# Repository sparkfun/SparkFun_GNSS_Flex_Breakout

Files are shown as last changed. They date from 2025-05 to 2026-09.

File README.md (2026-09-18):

SparkFun GNSS Flex Breakout
========================================

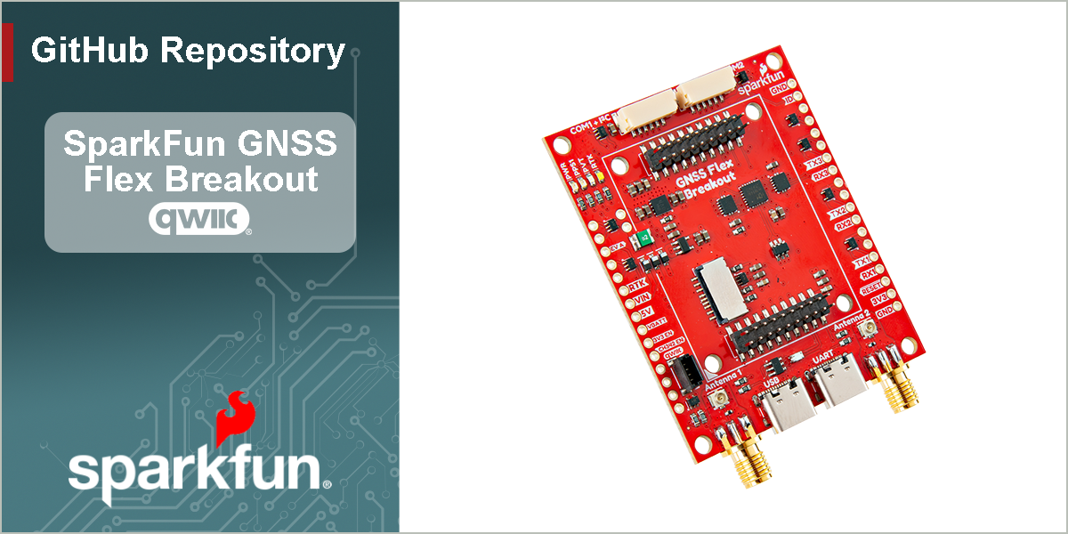
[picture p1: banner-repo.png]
SparkFun GNSS Flex Breakout


[*SparkFun GNSS Flex Breakout (GPS-28962)*](https://www.sparkfun.com/sparkfun-gnss-flex-breakout.html)

The [SparkFun GNSS Flex breakout](https://www.sparkfun.com/sparkfun-gnss-flex-breakout.html) is a *carrier board* for our GNSS Flex modules. In its simplest form, the GNSS Flex Breakout board provides access to all of the interfaces from a GNSS Flex module.

- Need access to all those UART pins? The Breakout provides that.
- Want to communicate with the GNSS directly over USB? You can do that too, if the GNSS module supports USB.

The GNSS Flex Breakout comes populated with two sets of 2x10 pin, 2mm pitch male headers for attaching a GNSS Flex module. With these headers, the GNSS Flex system is designed to be modular so that boards are pin-compatible for upgrades and can be easily swapped for repairs. Depending on the capabilities of the GNSS Flex module that is connected, these pins will breakout the USB, UART (x4), I^2^C, and SD card interfaces for the GNSS receiver along with any PPS (x2) or event (x2) signals, using a standardized pin out.

By default, the CH342 USB-to-Serial converter chip is connected to both the GNSS `UART1` and `UART2` interfaces. When you connect the `UART` USB port to your computer and install the driver, those two UART interfaces will appear as COM ports. If you need dedicated access to the `UART1` or `UART2` breakout pins, or want to use either of the JST connectors, you will need to disable the CH342. On this board, we have made this simple; just pull the `CH342 EN` breakout pin `LOW` or connect it to `GND`. Otherwise, there is also a `CH342 EN` jumper you can solder instead.

We have also included two 6-pin JST connectors, same as the ones used on Pixhawk flight controllers. The JST connectors allow you to: connect the GNSS to a Pixhawk; or connect a radio to the GNSS to transfer (e.g.) RTCM correction data. There are four LEDs indicators for power to the board and the `PPS1`, `PVT`, and `RTK` signals from the GNSS Flex module. Power can be provided by any or all of: the USB connectors or the `VIN` breakout pin. By default, Pin 1 of the JST connectors provides 5V output. But jumpers on the board allow the voltage to be changed to 3.3V. Or you can isolate the other power sources and connect an external 5V power input on Pin 1 instead. It is up to you.

> [!IMPORTANT]
> Depending on the GNSS Flex module, this product will likely require an external antenna:
>
> - Be sure to check out the hookup guide for more information on the GNSS Flex module.
> - Users can also find [GNSS Antennas](https://www.sparkfun.com/gnss/gnss-antennas.html) in our catalog.
>
> Users will have two options for connecting an external GNSS antenna to their GNSS receiver.
>
> - The GNSS Flex modules will usually come with a U.FL connector for external antenna.
> - For a sturdier connection, an SMA connector is available on the SparkFun GNSS Flex Breakout that is bridged to an U.FL connector. Users simply need to jumper the U.FL connectors on both the SparkPNT GNSS Flex module and SparkFun GNSS Flex Breakout with a short U.FL cable.

Documentation
--------------
- **[Hookup Guide (mkdocs)](http://docs.sparkfun.com/SparkFun_GNSS_Flex_System/)** - A hookup guide for the entire ecosystem of SparkFun GNSS Flex carrier boards and SparkPNT GNSS Flex modules, hosted by GitHub pages.<br>
   

Repository Contents
-------------------
- **[/docs](/docs/)** - Online documentation files
  - [/assets](/docs/assets/) - Assets files
    - [/3d_model](/docs/assets/3d_model/) - Files for the 3D models
      - [/3D CAD Model](/docs/assets/3d_model/cad_model.step) (.step)
    - [/board_files](/docs/assets/board_files/) - Files for the product design
      - [KiCad Design Files](/docs/assets/board_files/kicad_files.zip) (.zip)
      - [Schematic](/docs/assets/board_files/schematic.pdf) (.pdf)
      - [Dimensions](/docs/assets/board_files/dimensions.pdf) (.pdf)
    - [/component_documentation](/docs/assets/component_documentation/) - Datasheets for hardware components
    - [/img/hookup_guide/](/docs/assets/img/hookup_guide/) - Images for hookup guide documentation
- **[/Hardware](/Hardware/)** - Hardware design files (.brd, .sch)
  - **[/Production](/Production/)** - Production files

Product Variants
----------------
GNSS Flex *Carrier* Boards:

- [GPS-28962](https://www.sparkfun.com/sparkfun-gnss-flex-breakout.html) - GNSS Flex Breakout
- [GPS-28137](https://www.sparkfun.com/sparkfun-gnss-flex-phat.html) - GNSS Flex pHAT

Version History
---------------
- [v10](https://github.com/sparkfun/SparkFun_GNSS_Flex_Breakout/releases/tag/v10) - Initial Release
- [v11](https://github.com/sparkfun/SparkFun_GNSS_Flex_Breakout/releases/tag/v11) - Refactored the 3D model for new color adjustment script

License Information
-------------------

This product is ***open source***!

Please review the [`LICENSE.md`](./LICENSE.md) file for license information.

If you have any questions or concerns about licensing, please contact technical support on our [SparkFun forums](https://community.sparkfun.com/).

Distributed as-is; no warranty is given.

- Your friends at SparkFun.

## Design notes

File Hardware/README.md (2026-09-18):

SparkFun <PRODUCT NAME> Design Files
=====================================

The .sch and .brd files hare are Eagle CAD schematic and PCB design files from SparkFun Electronics.
A freeware version of Autodesk Eagle can be found [here](https://www.autodesk.com/products/eagle/free-download).

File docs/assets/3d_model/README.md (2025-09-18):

3d_model directory
====================
This folder should contain the 3D model of the product

## Solder Mask - Color Correction Values
Hex: #E0311D
RGB: 224, 49, 29

## File Optimizer
https://xiehangyun.github.io/gltf-optimization/

- Max Texture Size: 512
- Create Unified Palette Texture for Solid Colors and Merge: *(Unselect)*

## Model Editor
https://modelviewer.dev/editor/

## Old Methods

### File Converter - `*.wrl` to `*.glb`
https://imagetostl.com/convert/file/wrl/to/glb#convert

### Solder Mask - Color Correction
Open `*.glb` file and locate the `baseColorFactor` parameter with the following values:
```
          0.7027450799942017,
          0.1537254899740219,
          0.0909803956747055,
          0.8313725590705872
```
Replace those values with the following values: `[,,,1]`
```
          0.7418950796127319,
          0.0302486829459667,
          0.0122311776503920,
          1
```

### Solder Mask - Color Correction
https://3deditoronline.com/

### File Optimizer *(Deprecated)*
https://www.loci-labs.com/optimizer

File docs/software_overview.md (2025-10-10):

## USB Drivers
Depending on the GNSS Flex module that is attached, users may need to install specific USB driver. However, to access the UART interfaces through the `UART` USB-C connector, users will need to install the [CH342 USB driver](#ch342-usb-driver) below.

### CH342 USB Driver
The USB drivers for the CH342 USB-to-Serial converter can be downloaded from the [manufacturer's website](https://www.wch-ic.com/search?q=CH342&t=downloads).

<div class="grid cards" align="center" markdown>

-   :material-microsoft-windows: **Windows**

	---

	[:octicons-download-16:{ .heart } Download Page for `CH343SER.EXE`](https://www.wch-ic.com/downloads/CH343SER_EXE.html){ .md-button .md-button--primary target="blank" }

-   :material-apple: **MacOS**

	---

	[:octicons-download-16:{ .heart } Download Page for `CH341SER_MAC.ZIP`](https://www.wch-ic.com/downloads/CH34XSER_MAC_ZIP.html){ .md-button .md-button--primary target="blank" }

</div>

!!! info "Linux"
	A USB driver is not required for Linux based operating systems.

### GNSS Receiver
Some GNSS receivers may require a USB driver to be installed, before users can connect to its USB interface. For example, the ZED-X20P GNSS receiver does not require a USB drive to be installed to access its USB interface for development purposes; meanwhile, the mosaic-X5 GNSS receiver does require a USB driver to be installed before it can be connected to a Windows OS computer.

!!! info
	For more details on a specific GNSS Flex module, please refer to their [hookup guide](../modules.md).

## Manufacturer Software
Most of the manufacturers will provide software that is designed to specifically operate and configure their GNSS receivers. Often, this is the simplest way to get started with any development. The software usually provides a graphical interface for evaluating the GNSS receiver's performance, configuring any settings, and upgrading the firmware. Below are general software resources that might be useful; however, users should refer to the [hookup guide of their GNSS Flex module](../modules.md) for more details on a specific board.

<div class="grid cards" markdown>

- :septentrio:septentrio

	---

	On Windows & Linux platforms, Septentrio provides the RxTools software suite for their GNSS products:

	- [Software Page](https://www.septentrio.com/en/products/gps-gnss-receiver-software/rxtools)
	- [Download & User Manual](https://www.septentrio.com/en/products/gps-gnss-receiver-software/rxtools#resources)
	- [Tutorial Videos](https://www.youtube.com/playlist?list=PLUxLg2_PvvdHZ73CnfhS7ZePIIIUR7bON)

- <span class="twemoji enlarge-logo" style="width: 100%;">:quectel-primary:</span>

	---

	On Windows platforms, Quectel provides the QGNSS *(v2.0)* software application for their GNSS products:

	- [Download & User Manual](https://www.quectel.com/download/qgnss_v2-1_en/)
	- [GitHub Repository](https://github.com/quectel-open-source/GNSSTool)

- :ublox-primary:{ .icon-max-width }

	---

	On Windows platforms, u-blox provides the [u-center 2](https://www.u-blox.com/en/u-center-2) software application for their GNSS products:

	- [Software Page](https://www.u-blox.com/en/product/u-center)
	- [Download](https://u-center2-updates.u-blox.com/u-center2-installer.exe)
	- [User Manual](https://www.u-blox.com/en/info/u-center-2-user-guide)
	- [Webinar](https://www.youtube.com/watch?v=ZYttFyZ_7Uo)
	- [Tutorial Videos](https://www.youtube.com/watch?v=UY2XTb72SXA&list=PLSzSoRUA4EXuo9NTsbTnK84MiKvbVCEKt)

</div>

## Third-Party Software
In addition to any software provided by the manufacturers, there are a variety of third-party software options. The software implementation may even be unique to the available interfaces from an associated *carrier* board.

<div class="grid cards" markdown>

-   **PyGPSClient**

	---

	The `PyGPSClient` Python package is a graphical tool for evaluating the basic performance of GNSS receivers and is compatible with most of the major operating systems. The application parses and extrapolates a variety of data from the UART interface of GNSS receivers; with integrated support for the **NMEA**, **UBX**, **RTCM**, **NTRIP**, and **SPARTN** protocols. All GNSS information is then displayed neatly within its GUI for users to access or utilize.

	- [PyPI - Python Package](https://pypi.org/project/pygpsclient/)
	- [User Manual](https://www.semuconsulting.com/pygpsclient/index.html)
	- [GitHub Repository](https://github.com/semuconsulting/PyGPSClient)

</div>

### Installation
There are a variety of [installation methods](https://github.com/semuconsulting/PyGPSClient?tab=readme-ov-file#installation) detailed in the GitHub repository's `README.md` file. However, we recommend utilizing either the [`pip` installation method](https://github.com/semuconsulting/PyGPSClient?tab=readme-ov-file#install-using-pip). Depending on how Python is installed on the computer, one of the following commands should allow users to install the software:

```shell
python3 -m pip install pygpsclient
```

```shell
pip3 install pygpsclient
```

### NTRIP Client

<div class="grid" markdown>

<div markdown>

<figure markdown>
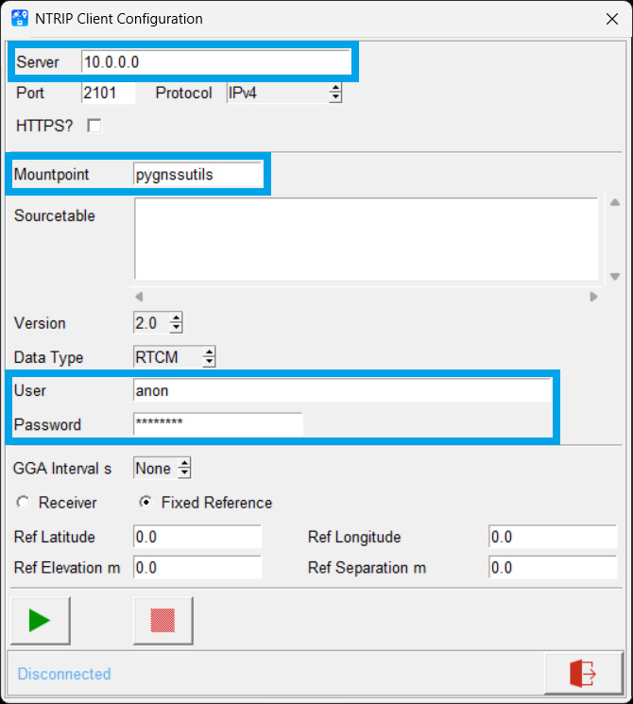
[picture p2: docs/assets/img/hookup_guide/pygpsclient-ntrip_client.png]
NTRIP server configurations

<figcaption markdown>Configuration settings for connecting to an NTRIP client.</figcaption>
</figure>

</div>

<div markdown>

To receive and process NTRIP RTK correction data from an NTRIP server in the PyGPSClient software, users can follow [these instructions](https://github.com/semuconsulting/PyGPSClient?tab=readme-ov-file#ntrip-client-facilities):

1. Click on the :material-satellite-uplink: icon, labeled `NTRIP Client`.
1. Enter the information for the network and mount point.
	- For an NTRIP server hosted by the `PyGPSClient` software:
		- **Server:** IP address of computer
		- **Port:** `2101`
		- **Mountpoint:** `pygnssutils`
		- **User:** `anon`
		- **Password:** `password`
1. Click on the :material-play: icon to connect to the server.

</div>

</div>

### NTRIP Server

<div class="grid" markdown>

<div markdown>

<figure markdown>
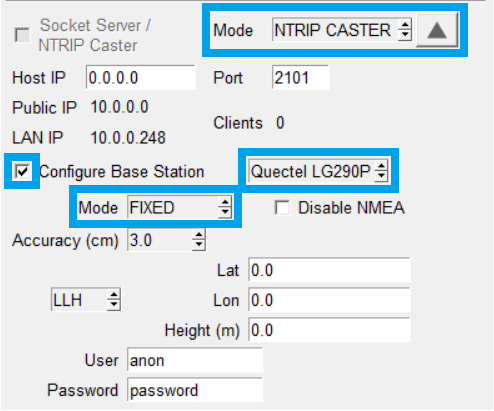
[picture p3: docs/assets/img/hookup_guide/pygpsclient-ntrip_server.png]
NTRIP server configurations

<figcaption markdown>Configuration settings for an NTRIP caster.</figcaption>
</figure>

</div>

<div markdown>

If their GNSS receiver is supported by NTRIP sever feature of the PyGPSClient software, users can follow [these instructions](https://github.com/semuconsulting/PyGPSClient?tab=readme-ov-file#socket-server--ntrip-caster-facilities) to setup their computer to operate as an NTRIP sever:

1. In the settings console, scroll to the bottom and select `NTRIP CASTER` from the **Mode** drop-down menu.
1. Select the box for `Configure Base Station` and select the GNSS receiver from the drop-down menu.
1. Select a mode of operation for the base station and provide the necessary information.
1. Select the box for `Socket Server/NTRIP Caster`.

</div>

</div>

## Arduino Libraries
There are some compatible Arduino libraries available for users interested in connecting their GNSS Flex module to a microcontroller.

### TinyGPS++ Library
For basic use cases, where users have already pre-configured their GNSS receiver, the [TinyGPS++ Arduino library](https://github.com/mikalhart/TinyGPSPlus) can be used to parse out pertinent data from the NMEA messages of their GNSS receiver. This is useful for extracting basic information, such as position, date, time, altitude, speed, and course from consumer GPS devices. This library can be installed from the library manager in the Arduino IDE by searching for:

	TinyGPSPlus

<div class="grid" markdown>

<div markdown>

<figure markdown>
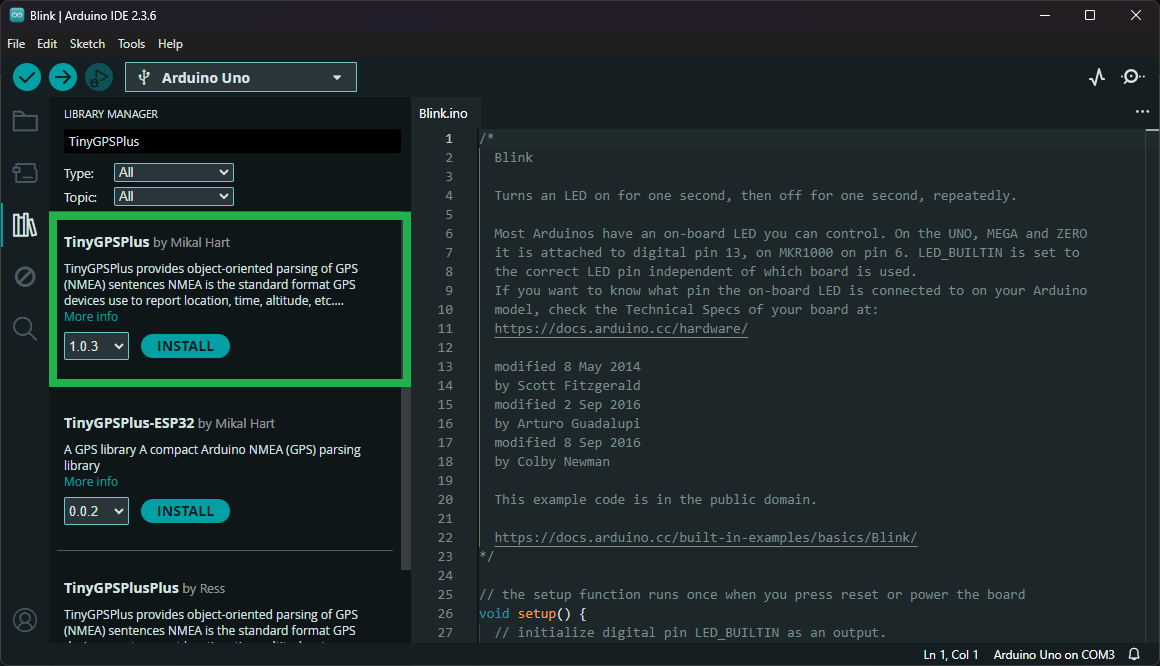
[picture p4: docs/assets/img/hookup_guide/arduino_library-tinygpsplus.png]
Library listed in the library manager of the Arduino IDE Click to enlarge

<figcaption markdown>The `TinyPGSPlus` Arduino library in the library manager of the Arduino IDE.</figcaption>
</figure>

</div>

<div markdown>

!!! tip "Manually Download the Arduino Library"
	For users who would like to manually download and install the library, the `*.zip` file can be accessed from the [GitHub repository](https://github.com/mikalhart/TinyGPSPlus) or downloaded by clicking the button below.

	<article style="text-align: center;" markdown>
	[:octicons-download-16:{ .heart } Download the Arduino Library](https://github.com/mikalhart/TinyGPSPlus/archive/refs/heads/master.zip){ .md-button .md-button--primary }
	</article>

</div>

</div>

### Receiver Specific Libraries
Some GNSS receivers may have a compatible Arduino library. As an example, the mosaic-X5 GNSS receiver has an inordinate amount of configuration parameters and is most readily configured through its web interface; therefore, an Arduino library hasn't been created for it. Whereas, the ZED-X20P GNSS receiver has a pre-existing [SparkFun u-blox GNSS v3](https://github.com/mikalhart/TinyGPSPlus) Arduino library that includes built-in examples, which the GNSS receiver is compatible with.

!!! info
	Please refer to the [hookup guide of your GNSS Flex module](../modules.md) for more details.

???+ note
	## mosaic-X5 Web Interface
	The mosaic-X5 GNSS module hosts an internal web server to configure and interact with the GNSS receiver. The default IP address allocated to the Ethernet-over-USB connection is `192.168.3.1`. This IP can be entered in any browser to open a connection to the receiver's web interface.

	<article class="video-500px" style="margin: auto;" markdown>
	<iframe src="https://www.youtube.com/embed/hrL5J6Q5gX8" title="Septentrio: Getting started with the Septentrio mosaic receiver module" frameborder="0" allow="accelerometer; autoplay; clipboard-write; encrypted-media; gyroscope; picture-in-picture" allowfullscreen></iframe>
	</article>

	!!! info
		The default IP address cannot be changed; this feature is only to be used when a single receiver is connected to your computer.

	### Sharing Internet Access
	By default, the mosaic-X5 GNSS receiver is not configured to access the internet through the USB interface. In order to receive or cast RTK corrections to/from a RTK network, such as NTRIP, users will need to enable this capability.

	- Users will need to use the web interface or RxTool software suite to enable the `Outgoing Internet Access Over USB` from the **Communication** > **USB** drop-down menu of the navigation tabs.
	- This also requires users to allowing Internet sharing through on their computer as well. The procedure to do so depends on your operating system.
		- On a Windows PC, users must enable `Allow other network users to connect through this computer's Internet connection`, through the properties option of the network adapter with internet access.
		- On a Linux computer, users will likely need to configure a [network bridge](https://en.wikipedia.org/wiki/Network_bridge).

	<article class="video-500px" style="margin: auto;" markdown>
	<iframe src="https://www.youtube.com/embed/bUt8cL9Ue1Y" title="Septentrio: Share internet connection with your GNSS / GPS receiver over USB" frameborder="0" allow="accelerometer; autoplay; clipboard-write; encrypted-media; gyroscope; picture-in-picture" allowfullscreen></iframe>
	</article>

	!!! info "New IP Address"
		Once a network bridge is enabled, the receiver will receive its IP address from the computer's DHCP server. Depending on the routing table, the module may no longer be reachable at its default IP address *(`192.168.3.1`)*.

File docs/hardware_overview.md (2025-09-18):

<article style="text-align: center;" markdown>
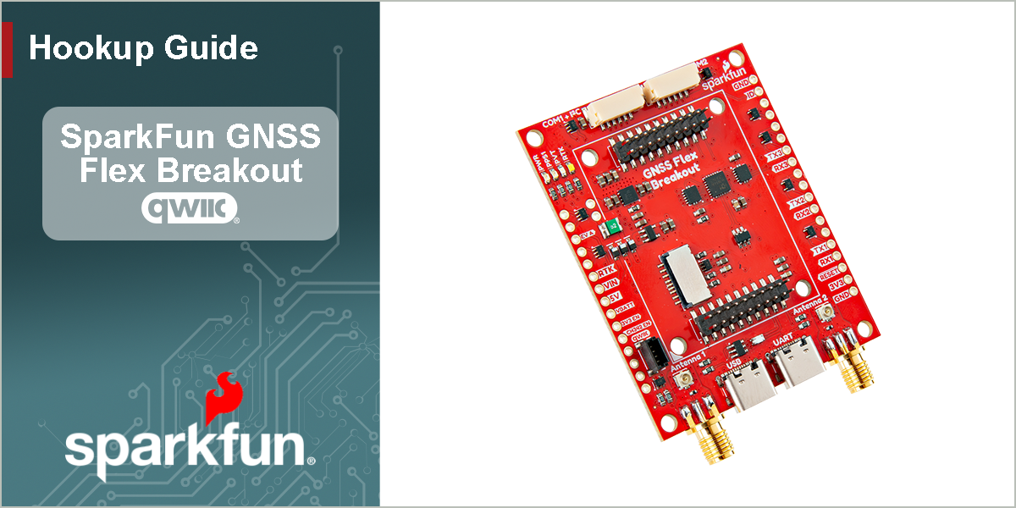
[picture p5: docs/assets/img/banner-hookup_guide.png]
Banner

</article>

## Introduction

<div class="grid cards desc" markdown>

-   <a href="https://www.sparkfun.com/sparkfun-gnss-flex-breakout.html">
	**SparkFun GNSS Flex Breakout**<br>
	**SKU:** GPS-28137

	---

	<figure markdown>
	Product Thumbnail
	</figure></a>

	<article style="text-align: center;" markdown>
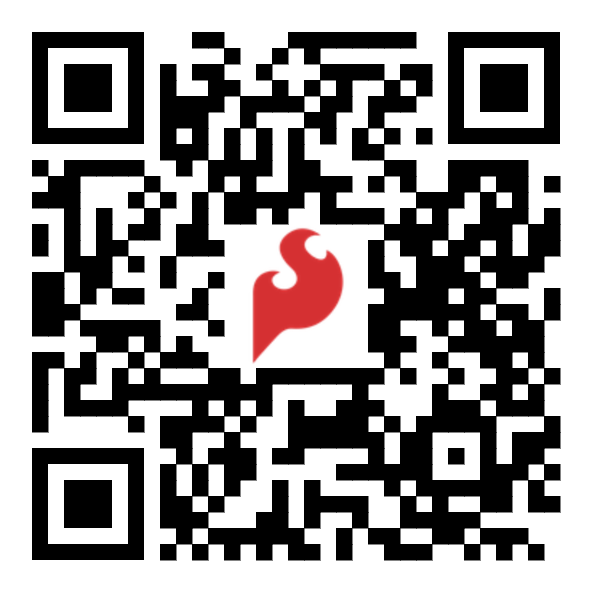
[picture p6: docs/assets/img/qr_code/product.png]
QR code to product page
	
	[Purchase from SparkFun :fontawesome-solid-cart-plus:{ .heart }](https://www.sparkfun.com/sparkfun-gnss-flex-breakout.html){ .md-button .md-button--primary }
	</article>

-	The SparkFun GNSS Flex Breakout board is a [*carrier board*](../carriers.md) for our [SparkPNT GNSS Flex modules](../modules.md). With pre-soldered headers, the GNSS Flex Breakout board provides access to all of the interfaces from a GNSS Flex module. We have also included two 6-pin JST connectors, same as the ones used on Pixhawk flight controllers. The JST connectors allow you to: connect the GNSS to a Pixhawk; or connect a radio to transfer RTCM correction data. Power can be provided by any or all of: the USB connectors or the `VIN` breakout pin.

	The GNSS Flex Breakout comes populated with two sets of 2x10 pin, 2mm pitch male headers for attaching a GNSS Flex module. With these headers, the GNSS Flex system is designed to be modular so that boards are pin-compatible for upgrades and can be easily swapped for repairs. Depending on the capabilities of the GNSS Flex module that is connected, these pins will breakout the USB, UART (x4), I^2^C, and SD card interfaces for the GNSS receiver along with any PPS (x2) or event (x2) signals, using a standardized pin out. There board also has four LEDs indicators for power and the `PPS1`, `PVT`, and `RTK` signals from the GNSS Flex module.

	!!! note
		By default, the CH342 USB-to-Serial converter chip is connected to both the GNSS `UART1` and `UART2` interfaces. When you connect the `UART` USB port to your computer and install the driver, those two UART interfaces will appear as COM ports. If you need dedicated access to the `UART1` or `UART2` breakout pins, or want to use either of the JST connectors, you will need to disable the CH342. On this board, we have made this simple; just pull the `CH342 EN` breakout pin `LOW` or connect it to `GND`. Otherwise, there is also a `CH342 EN` jumper you can solder instead.

		By default, Pin 1 of the JST connectors provides 5V output. But jumpers on the board allow the voltage to be changed to 3.3V. Or you can isolate the other power sources and connect an external 5V power input on Pin 1 instead. It is up to you.
	
</div>

## Design Files

<!-- Import the component -->
<script type="module" src="https://ajax.googleapis.com/ajax/libs/model-viewer/3.5.0/model-viewer.min.js"></script>

<div class="grid cards desc" markdown>

-   :kicad-primary:{ .enlarge-logo } **Design Files**

	---

	- :fontawesome-solid-file-pdf: [Schematic](./assets/board_files/schematic.pdf)
	- :material-folder-zip: [KiCad Files](./assets/board_files/kicad_files.zip)
	- :material-rotate-3d: [STEP File](./assets/3d_model/cad_model.step)
	- :fontawesome-solid-file-pdf: [Board Dimensions](./assets/board_files/dimensions.pdf):

-   <!-- Boxes in tabs -->

	=== "3D Model"
		<article style="text-align: center;" markdown>
		<model-viewer src="../assets/3d_model/web_model.glb" camera-controls poster="../assets/3d_model/poster.png" tone-mapping="neutral" shadow-intensity="2" shadow-softness="0.2" camera-orbit="0deg 75deg 0.1623m" field-of-view="25.11deg" style="width: 100%; height: 450px;">
		</model-viewer>
		</article>

		???+ tip "Manipulate 3D Model"
			<article style="text-align: center;" markdown>

			| Controls       | Mouse                    | Touchscreen    |
			| :------------- | :----------------------: | :------------: |
			| Zoom           | Scroll Wheel             | 2-Finger Pinch |
			| Rotate         | ++"Left-Click"++ & Drag  | 1-Finger Drag  |
			| Move/Translate | ++"Right-Click"++ & Drag | 2-Finger Drag  |

			</article>

	=== "Dimensions"
		<article style="text-align: center;" markdown>
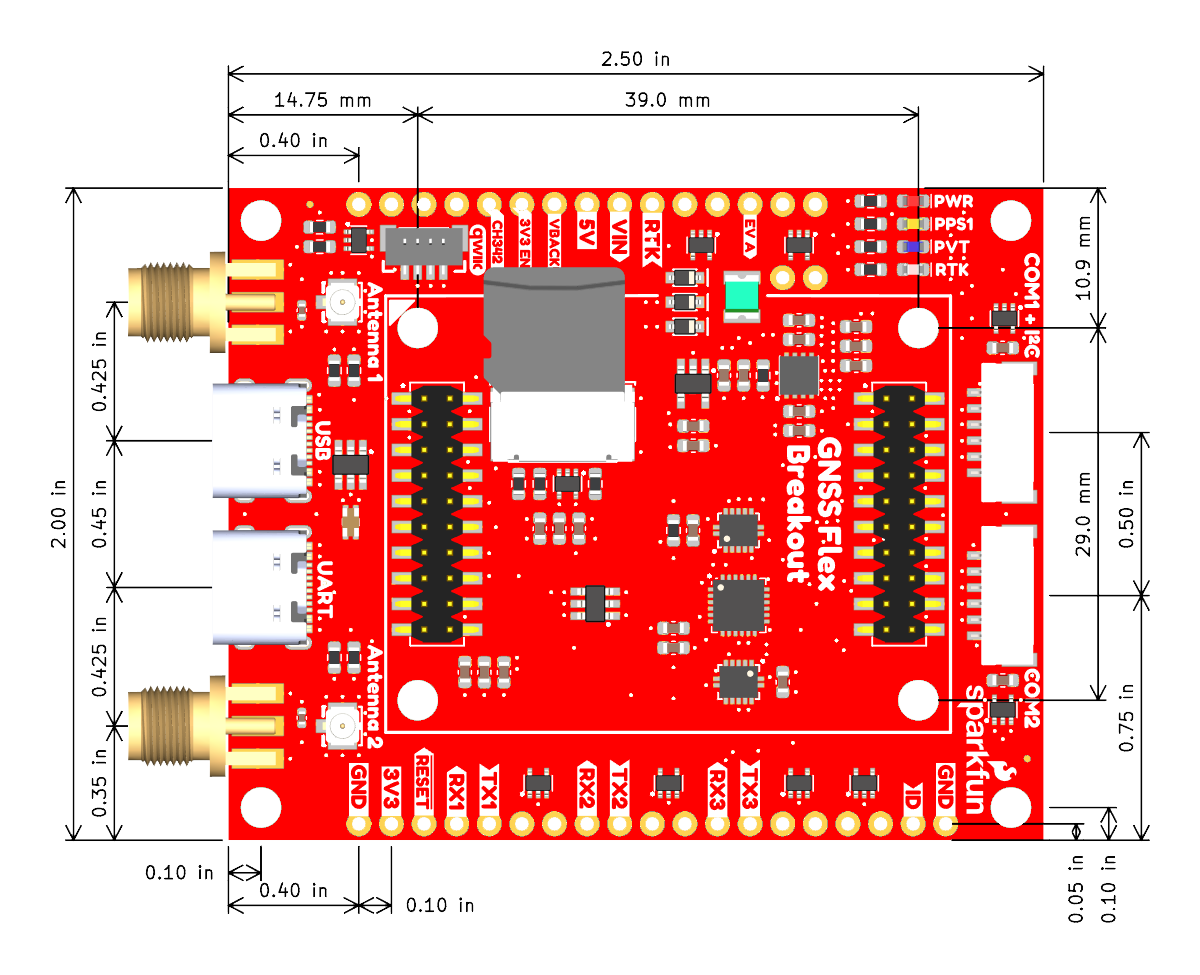
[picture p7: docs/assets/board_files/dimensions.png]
Board Dimensions
		
		<figcaption markdown>Dimensions of the GNSS Flex Breakout board.</figcaption>
		</article>

		???+ tip "Need more measurements?"
			For more information about the board's dimensions, users can download the [KiCad files](./assets/board_files/kicad_files.zip) for this board. These files can be opened in KiCad and additional measurements can be made with the measuring tool.

			!!! info ":octicons-download-16:{ .heart } KiCad - Free Download!"
				KiCad is free, open-source [CAD]("computer-aided design") program for electronics. Click on the button below to download their software. *(\*Users can find out more information about KiCad from their [website](https://www.kicad.org/).)*

				<article style="text-align: center;" markdown>
				[Download :kicad-primary:{ .enlarge-logo }](https://www.kicad.org/download/ "Go to downloads page"){ .md-button .md-button--primary }
				</article>

			???+ info ":straight_ruler: Measuring Tool"
				This video demonstrates how to utilize the dimensions tool in KiCad, to include additional measurements:

				<article class="video-500px" style="text-align: center; margin: auto;" markdown>
				<iframe src="https://www.youtube.com/embed/-eXuD8pkCYw" title="KiCad Dimension Tool" frameborder="0" allow="accelerometer; autoplay; clipboard-write; encrypted-media; gyroscope; picture-in-picture" allowfullscreen></iframe>
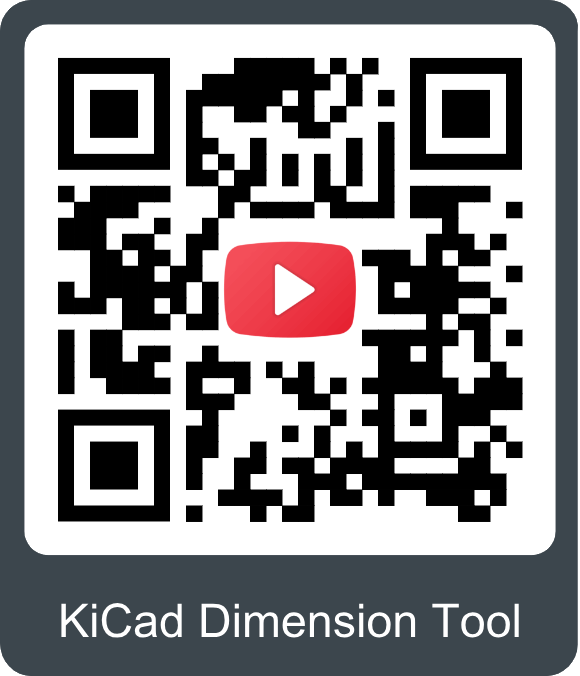
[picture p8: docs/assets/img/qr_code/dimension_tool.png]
QR code to play video
				
				</article>

</div>

## Board Layout
The GNSS Flex system is designed around two 2x10-pin, 2mm pitch headers used mate the two types of boards. A standardized pin layout, keeps the ecosystem pin-compatible for upgrades and allows board to be easily swapped for repairs. Depending on the capabilities of the GNSS receiver, these pins will breakout the USB, UART (x4), I^2^C, and SD card interfaces along with any PPS or event signals of the GNSS receiver.

<div class="grid" markdown>

<div markdown>

<figure markdown>
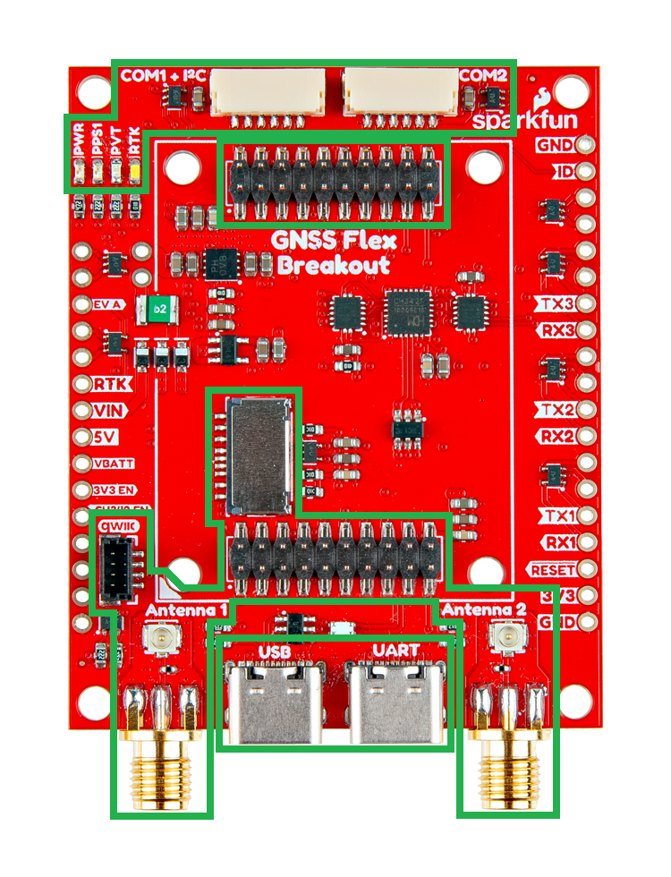
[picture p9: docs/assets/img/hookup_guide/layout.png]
Board Layout

<figcaption markdown>Layout of the major components of the GNSS Flex Breakout board.</figcaption>
</figure>

</div>

<div markdown>

The GNSS Flex Breakout has the following features:

1. **GNSS Flex Headers**
:   Two sets of 2x10 pin, 2mm pitch female headers for connecting a GNSS Flex module.
1. **Alignment Indicator**
:   Used to indicate the board alignment of a GNSS Flex module.
1. **Signal Bridges**
:   Two U.FL-to-SMA signal bridges, provide on-board adapters for connecting an external GNSS antenna(s) or another input/output signal(s).
1. **Status LEDs**
:   Four status indication LEDs for the attached GNSS Flex module.
1. **USB-C Connectors**
:   Used to access the USB and `UART1`/`UART2` interfaces of a GNSS Flex Module.
1. **JST Connectors**
:   Breaks out the `UART1`, `UART2`, and  I^2^C, and interfaces of a GNSS Flex Module to connect a PixHawk controller or [telemetry radio](https://www.sparkfun.com/sik-telemetry-radio-v3-915mhz-100mw.html).
1. **SD Card Slot**
:   Depending on the capabilities of the GNSS Flex module, a &micro;SD card slot is available for data logging.
1. **Qwiic Connector**
:   Depending on the capabilities of the GNSS Flex module, a Qwiic connector is available for connecting to a controller.

</div>

</div>

## USB Connectors
Depending on the capabilities of the GNSS receiver, the USB connectors will break out the USB interface and/or UART interfaces from the GNSS Flex module.

<div class="grid" markdown>

<div markdown>

<figure markdown>
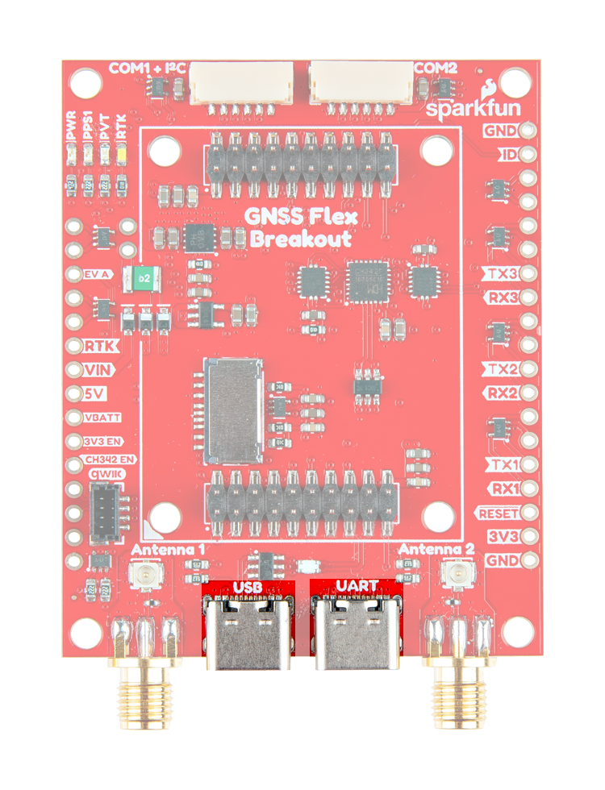
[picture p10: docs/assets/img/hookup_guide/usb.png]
USB connectors

<figcaption markdown>The USB connectors on the GNSS Flex Breakout board.</figcaption>
</figure>

</div>

<div markdown>

- `USB` USB-C connector
	- If available, connects directly w/ GNSS Flex Module's USB interface
	- 5V power input
- `UART` USB-C connector
	- Interfaces to `UART1` and `UART2` on the GNSS Flex Module via a CH342 USB-to-Serial converter
	- 5V power input

	!!! info
		To utilize the [PTH](https://en.wikipedia.org/wiki/Through-hole_technology "Plated Through Holes") pins or JST connections of the `UART1` and `UART2` interfaces, the CH342 USB-to-Serial converter must be disabled with either the [`CH342 EN` jumper](#jumpers) or the `CH342 EN` PTH pin.

</div>

</div>

## SMA Connectors
The SMA connectors, provide users with a more robust connection for interfacing with signals to/from the GNSS Flex module. Each pair of U.FL and SMA connectors are bridged together and their ground plane isolated from the rest of the board, this allows users to pass signals between the GNSS Flex module and the GNSS Flex Breakout board. On the GNSS Flex Breakout board, we provide two sets of signal bridges. These signal bridges will primarily be used to attach an external GNSS antenna for their GNSS Flex module.

<figure markdown>
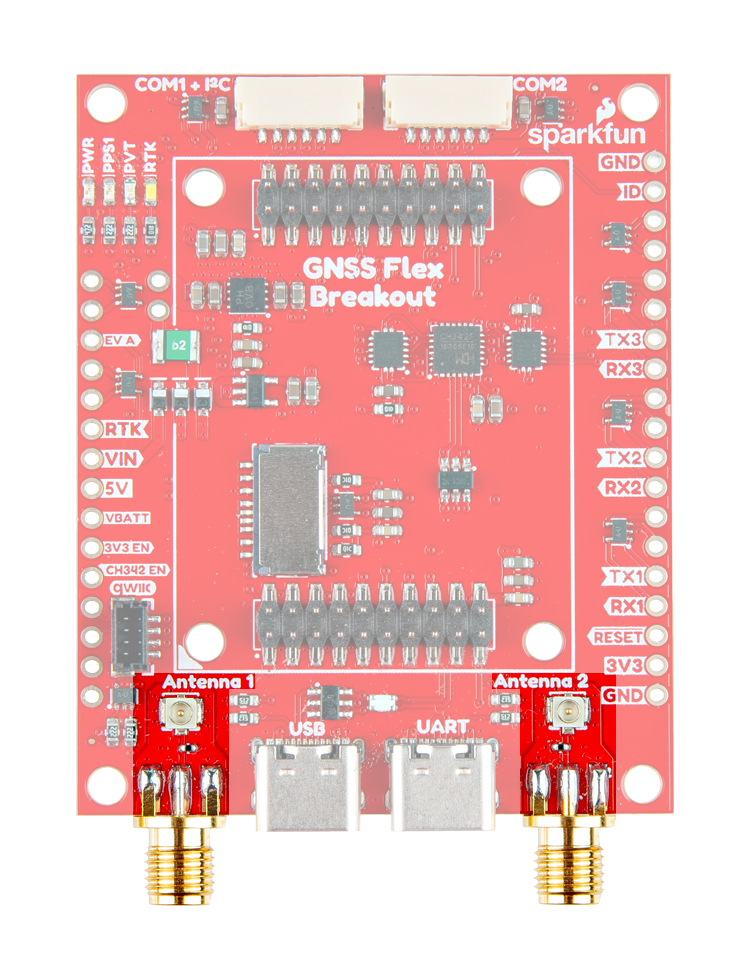
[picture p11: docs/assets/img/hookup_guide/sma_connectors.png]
Signal bridges

<figcaption markdown>The RF signal bridges on the GNSS Flex Breakout, which provides a more robust SMA connection.</figcaption>
</figure>

## Breakout Pins
The primary function of the SparkFun GNSS Flex Breakout board is to expose the interfaces of the GNSS Flex modules. Most of which, are provided through the [PTH](https://en.wikipedia.org/wiki/Through-hole_technology "Plated Through Holes") pins.

<div class="grid cards" markdown>

<div markdown>

<figure markdown>
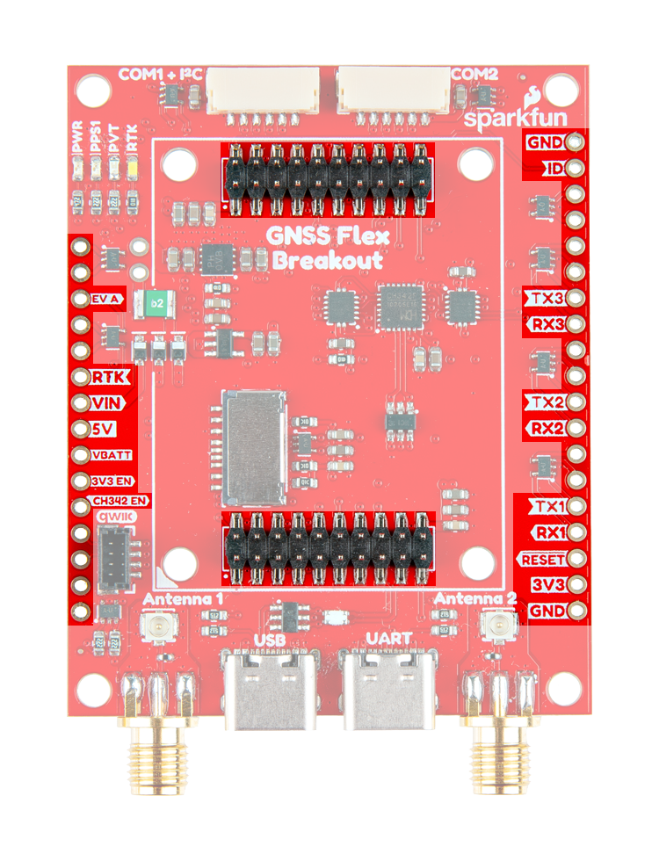
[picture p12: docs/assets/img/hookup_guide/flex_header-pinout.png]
Breakout pins

<figcaption markdown>The breakout pins on the board connected to the Flex header system.</figcaption>
</figure>

</div>

<div markdown>

Breakout Pins and Exposed Interfaces:

- Power Pins
	- VIN
	- 5V
	- 3.3V
	- 3.3V Enable
	- Backup power
	- Reset
- USB data
- UART (x4)
- SD card *(see [SD Card Slot](#sd-card-slot))*
- I^2^C bus
- PPS signals (x2)
- Status indicators (x2)
- Event triggers (x2)
- ID pin

</div>

</div>

### Power
The simplest method to power the GNSS Flex breakout board is through the USB-C connectors. However, only **3.3V** is required to power an attached GNSS Flex module; the 5V is only utilized for the USB interface and to power the JST connectors.

<div class="grid cards" markdown>

<div markdown>

<figure markdown>
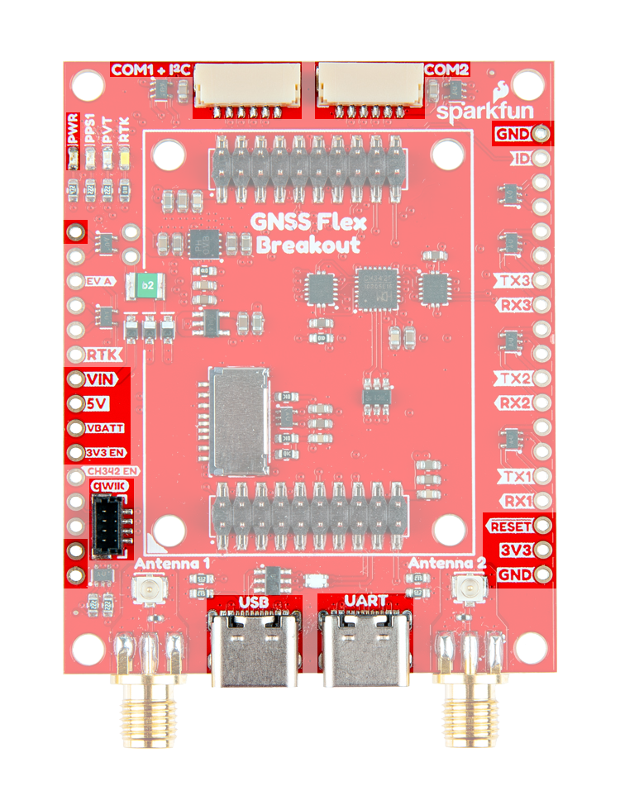
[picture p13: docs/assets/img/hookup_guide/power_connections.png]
Power connections

<figcaption markdown>The GNSS Flex breakout board's power connections.</figcaption>
</figure>

</div>

<div markdown>

Below, is a general summary of the power circuitry on the board; most are broken out as [PTH](https://en.wikipedia.org/wiki/Through-hole_technology "Plated Through Holes") pins:

<article class="annotate" markdown>

- Power Supplies - Power sources for the entire board
	- **`VIN`** - The general input voltage
	- **`5V`** - The voltage from the USB-C connector, usually **5V**.
		- Input Voltage Range: 2.2 - 5.5V (1)
		- Powers the 3.3V voltage regulators
			- [AP7361C](./assets/component_documentation/AP7361C.pdf), which can source up to 1.5A
			- [RT9080](./assets/component_documentation/RT9080.pdf), which can source up to 600mA
		- They also power the [JST connectors](#jst-connectors)
- **`3V3`** - Provides a regulated 3.3V from the [AP7361C](./assets/component_documentation/AP7361C.pdf), using the power supplied from the `VIN`, `5V`, and/or USB-C connectors
	- Used to power the GNSSS Flex module, LEDs, and [Qwiic connectors](#qwiic-connector)
	- Controlled by the `3V3 EN` pin, which is enabled by default
- **`3V3 EN`** - Enables the voltage output from the [AP7361C](./assets/component_documentation/AP7361C.pdf), 3.3V voltage regulator
	- Enabled by default *(active `HIGH`)*
- **`VBACKUP`** - Provides a regulated 3.3V from the [RT9080](./assets/component_documentation/RT9080.pdf), using the power supplied from the `VIN`, `5V`, and/or USB-C connectors
	- Provides backup power to the GNSS Flex module to maintain ephemeris data for warm starts
- **`RESET`** - Used to reset the GNSS Flex module
- **`GND`** - The common ground or the 0V reference for the voltage supplies.

</article>

1. The [RT9080](./assets/component_documentation/RT9080.pdf) LDO regulator has an input voltage range of 1.2 - 5.5V and the [AP7361C](./assets/component_documentation/AP7361C.pdf) LDO regulator has an input voltage range of 2.2 - 6.0V. A minimum supply voltage of **3.5V** is recommended for a 3.3V output.

</div>

</div>

!!! warning "Backup Battery"
	When connecting an external battery or power source to the `VBACKUP` pin, users should disconnect the [`VBACKUP` jumper](#jumpers).

!!! tip "JST Connector"
	The `VOUT` pins for the [JST connectors](#jst-connectors) are designed to operate as a voltage output. However, an input voltage can be supplied through the pin, but users should be mindful of any voltage contention issues.

	Additionally, the [jumper for the `VOUT` pin](#jumpers) can be modified to change to output voltage level.

!!! info
	For more details, users can reference the [schematic](./assets/board_files/schematic.pdf) and the datasheets of the individual components on the board.

### Interfaces
The following interfaces and signals of the GNSS Flex system are connected to the 40-pin female GPIO header of the GNSS Flex Breakout board. Below, are tables detailing the pin connections for each interface.

=== "USB"
	If available, the `USB` interface of the GNSS Flex module can be accessed through the `USB` USB-C connector.

	<figure markdown>
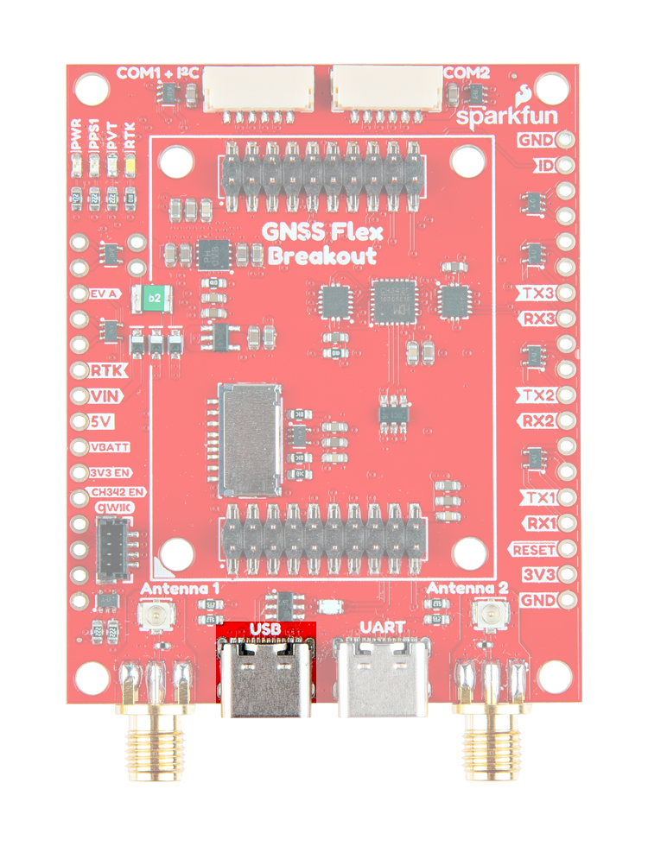
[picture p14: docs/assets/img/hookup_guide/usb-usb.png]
USB interface
	
	<figcaption markdown>The USB interface from the GNSS Flex system on the GNSS Flex breakout board.</figcaption>
	</figure>

=== "UART"

	!!! tip "UART Numbering"
		Please note that the UART numbers (`UART1` - `UART4`) listed below follows the GNSS Flex Module UART numbering scheme.

	<div class="grid cards" markdown>

	<div markdown>

	<figure markdown>
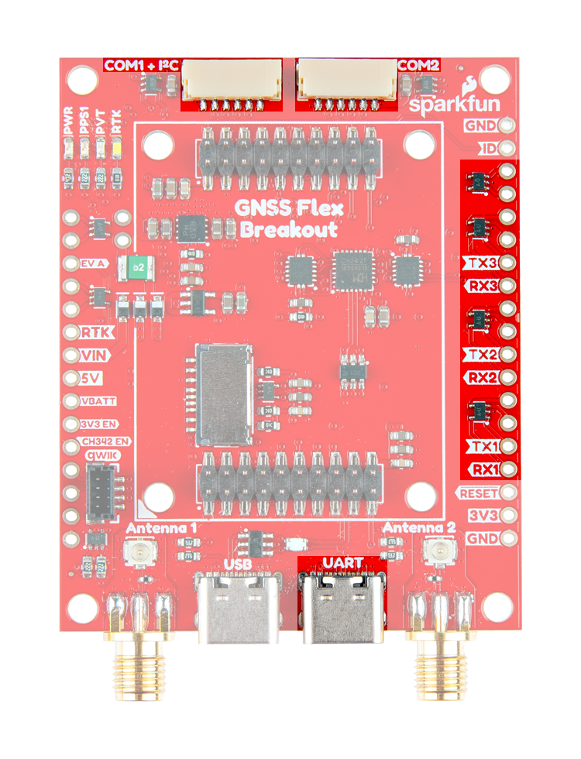
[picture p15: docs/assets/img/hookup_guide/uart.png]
UART interfaces
	
	<figcaption markdown>The pin connections of the UART interfaces, from the GNSS Flex system on the GNSS Flex breakout board.</figcaption>
	</figure>

	</div>

	<div markdown>

	`UART1`
	:   The `UART1` interface can be accessed through either the `UART` USB-C connector, <code>COM1 + I^2^C</code> JST connector, or `RX1`/`TX1`/`CTS1`/`RTS1` set of [PTH](https://en.wikipedia.org/wiki/Through-hole_technology "Plated Through Holes") pins. However, in order to utilize the <code>COM1 + I^2^C</code> JST connector or `RX1`/`TX1`/`CTS1`/`RTS1` PTH pins, the CH342 must be disabled using either the [`CH342 EN` jumper](#jumpers) or the `CH342 EN` PTH pin.

	`UART2`
	:   The `UART2` interface can be accessed through either the `UART` USB-C connector, `COM2` JST connector, or `RX2`/`TX2`/`CTS2`/`RTS2` set of [PTH](https://en.wikipedia.org/wiki/Through-hole_technology "Plated Through Holes") pins. However, in order to utilize the `COM2` JST connector or `RX2`/`TX2`/`CTS2`/`RTS2` PTH pins, the CH342 must be disabled using either the [`CH342 EN` jumper](#jumpers) or the `CH342 EN` PTH pin.

	`UART3`
	:   The `UART3` interface can be accessed through the `RX3`/`TX3`/`CTS3`/`RTS3` set of [PTH](https://en.wikipedia.org/wiki/Through-hole_technology "Plated Through Holes") pins.

	`UART4`
	:   The `UART4` interface can be accessed through the `RX4`/`TX4` [PTH](https://en.wikipedia.org/wiki/Through-hole_technology "Plated Through Holes") pins.

	</div>

	</div>

=== "I^2^C"
	The I^2^C interface can be accessed through either the Qwiic connector, <code>COM1 + I^2^C</code> JST connector, or `SCL`/`SDA` [PTH](https://en.wikipedia.org/wiki/Through-hole_technology "Plated Through Holes") pins. Depending on how the I^2^C bus is configured, users may need to use pull-up resistors, which can be enabled with the [`I^2^C` jumper](#jumpers).

	<figure markdown>
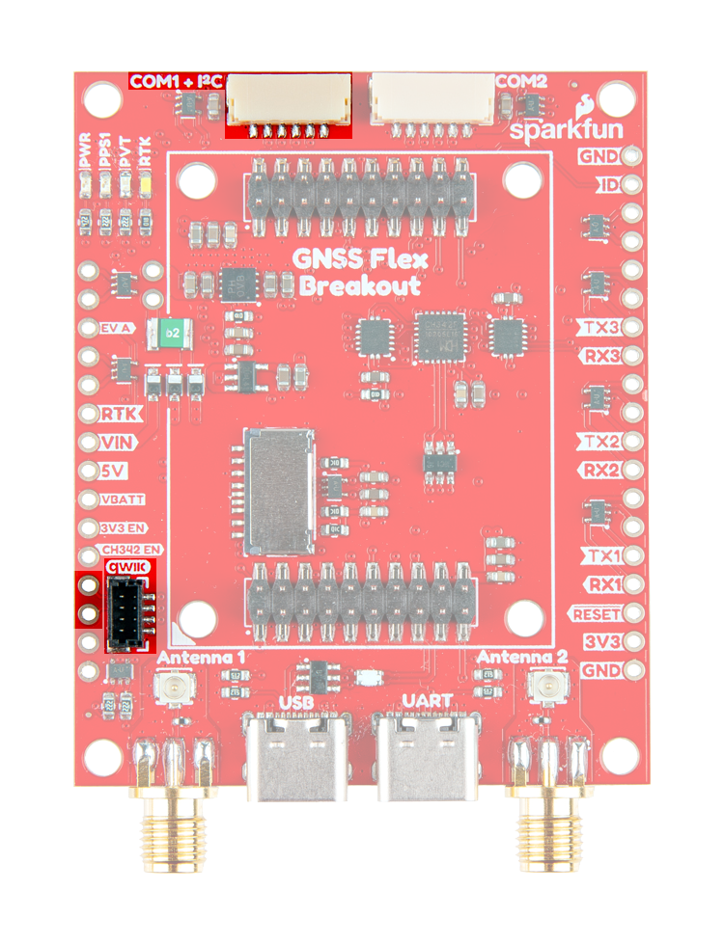
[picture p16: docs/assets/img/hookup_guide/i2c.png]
I2C interface
	
	<figcaption markdown>The pin connections of the I^2^C interface, from the GNSS Flex system on the GNSS Flex breakout board.</figcaption>
	</figure>

=== "PPS Signals"
	The two [`PPS`](https://en.wikipedia.org/wiki/Pulse-per-second_signal "Pulse Per Second") signals can be accessed through the `PPS1` and `PPS2` [PTH](https://en.wikipedia.org/wiki/Through-hole_technology "Plated Through Holes") pins. The `PPS1` pin is also connected to the [`PPS` LED](#leds), which can be disabled with a [jumper](#jumpers) for low power applications.

	<figure markdown>
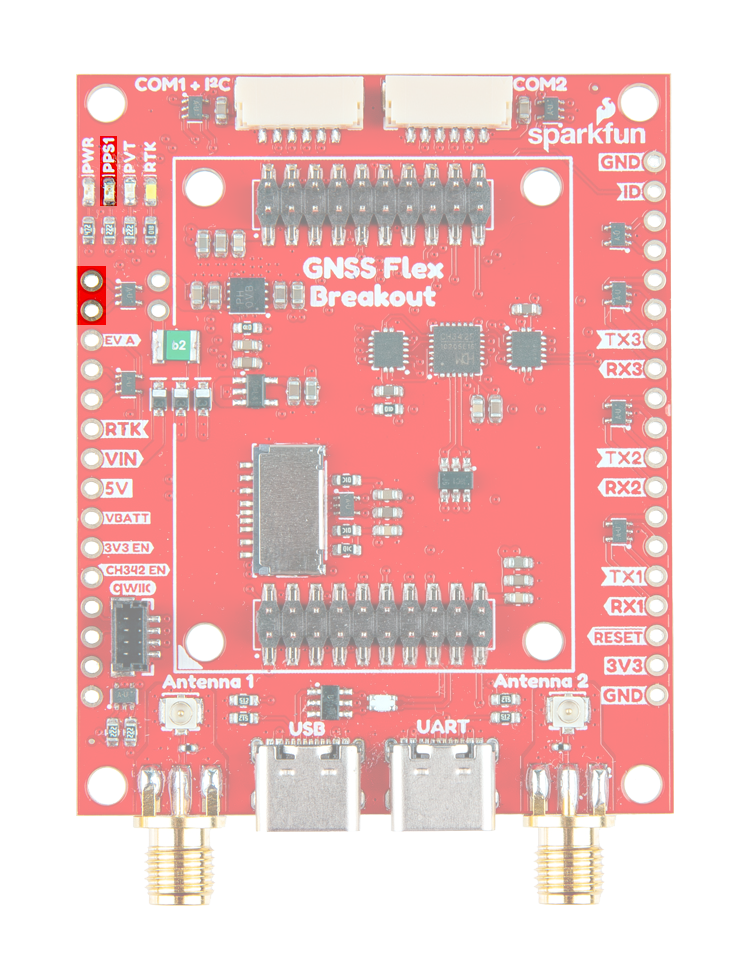
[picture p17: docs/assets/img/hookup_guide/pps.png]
PPS signals
	
	<figcaption markdown>The pin connections of the PPS signals, from the GNSS Flex system on the GNSS Flex breakout board.</figcaption>
	</figure>

=== "Event Triggers"
	The two event triggers can be accessed through the `EVENTA` and `EVENTB` [PTH](https://en.wikipedia.org/wiki/Through-hole_technology "Plated Through Holes") pins.

	<figure markdown>
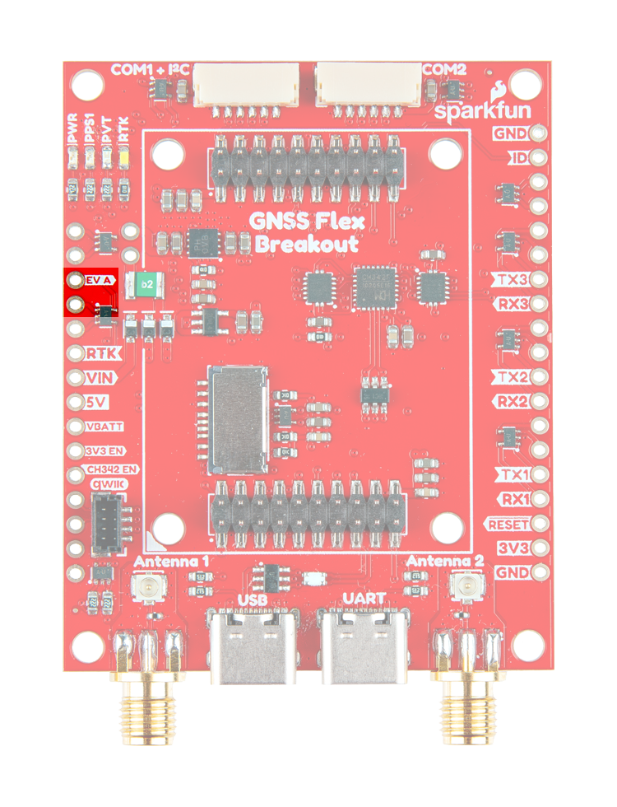
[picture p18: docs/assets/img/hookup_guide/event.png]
Event triggers
	
	<figcaption markdown>The pin connections of the event triggers, from the GNSS Flex system on the GNSS Flex breakout board.</figcaption>
	</figure>

=== "Status Indicators"
	There are two status indicators, which can be accessed through the `PVT` and `RTK` [PTH](https://en.wikipedia.org/wiki/Through-hole_technology "Plated Through Holes") pins. These pins are also connected to the [`PVT` and `RTK` LEDs](#leds), which can be disabled with their [respective jumpers](#jumpers) for low power applications.

	<figure markdown>
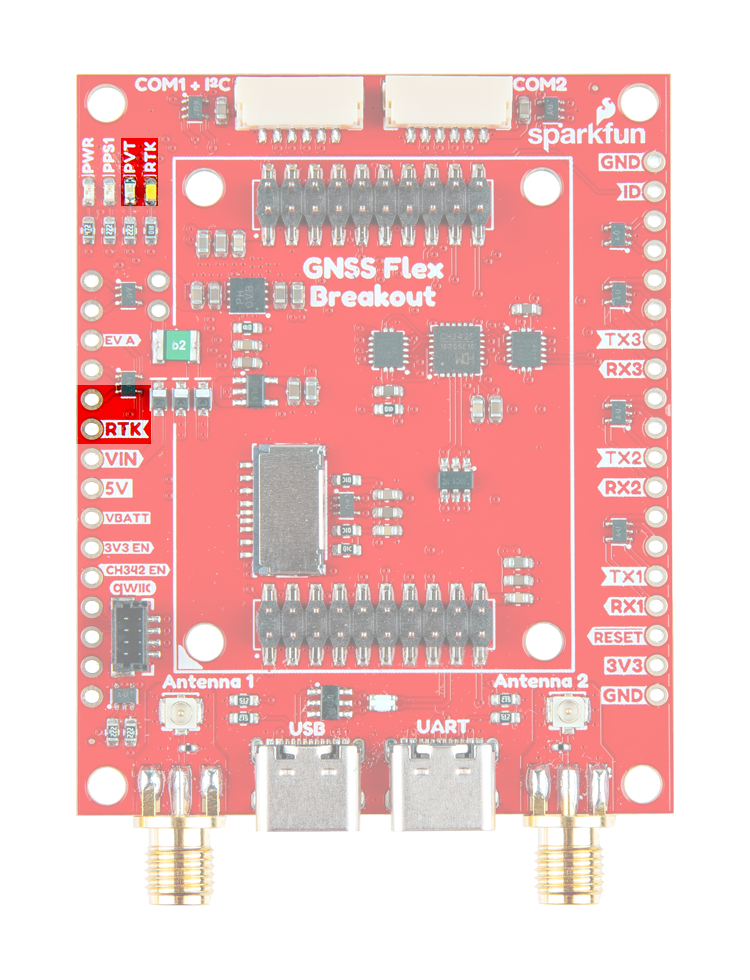
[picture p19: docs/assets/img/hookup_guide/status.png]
Status indicators
	
	<figcaption markdown>The pin connections of the status indicators, from the GNSS Flex system on the GNSS Flex breakout board.</figcaption>
	</figure>

=== "ID Pin"
	The `ID` pin can be utilized to identify the GNSS receiver of a connected GNSS Flex module.

	<div class="grid cards" markdown>

	<div markdown>

	<figure markdown>
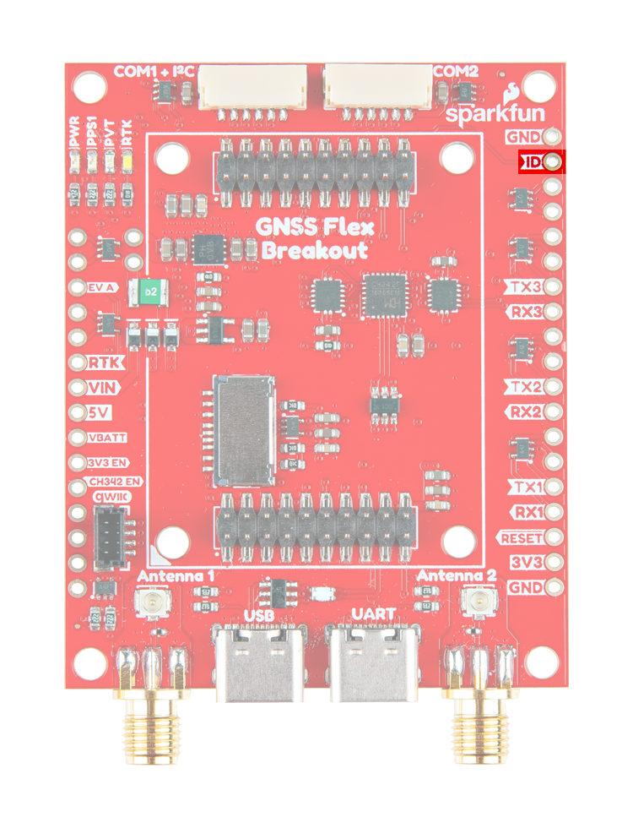
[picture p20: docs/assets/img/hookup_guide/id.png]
ID pin
	
	<figcaption markdown>The `ID` pin from the GNSS Flex system, used to identify a connected GNSS Flex module.</figcaption>
	</figure>

	</div>

	<div markdown>

	<article style="text-align: center;" markdown>

	| GNSS Flex Module | ID Resistors            | ID Value |
	| :--------------: | :---------------------: | :------: |
	| mosaic-X5        | 1.0k&ohm; + 47.0k&ohm;  | 0.06875V |
	| LG290P           | 3.3k&ohm; + 10.0k&ohm;  | 0.81880V |
	| DAN-F10          | 5.62k&ohm; + 6.8k&ohm;  | 1.49324V |
	| ZED-X20P         | 15.0k&ohm; + 12.1k&ohm; | 1.82657V |

	</article>

	</div>

	</div>

## LEDs
There are four status LEDs on the GNSS Flex Breakout:

<div class="grid" markdown>

<div markdown>

<figure markdown>
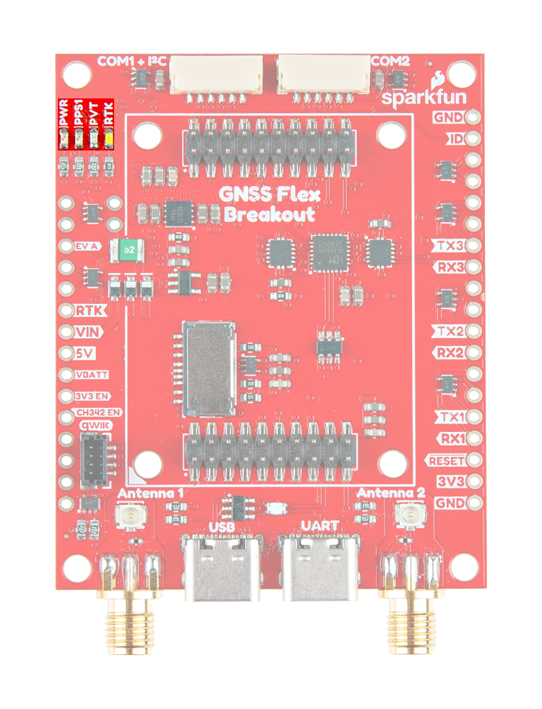
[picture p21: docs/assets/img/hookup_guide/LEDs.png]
Status LEDs

<figcaption markdown>The status LED indicators on the GNSS Flex Breakout board.</figcaption>
</figure>

</div>

<div markdown>

- `PWR` - Power *(Red)*
	- Turns on once power is supplied to the board
- `PPS` - Pulse-Per-Second *(Yellow)*
	- Indicates when there is a pulse-per-second signal from the GNSS Flex module
- `RTK` - RTK *(White)*
	- Usually indicates when an RTK fix has been established or when the correct RTCM data is being received by the GNSS Flex module
- `PVT` - PVT *(Blue)*
	- Usually indicates when an GNSS lock or a position fix has been established by the GNSS Flex module

!!! info
	For low power applications, the LEDs can be disabled to conserve energy. *See the [**Jumpers** section](#jumpers).*

</div>

</div>

## JST Connectors
There are two locking JST-GH connectors to easily access the UART and I^2^C interfaces of the GNSS Flex headers. Depending on the capabilities of the GNSS Flex module, the UART and I^2^C interfaces could be used to configure and communicate with the GNSS receiver.

<div class="grid" markdown>

<div markdown>

<figure markdown>
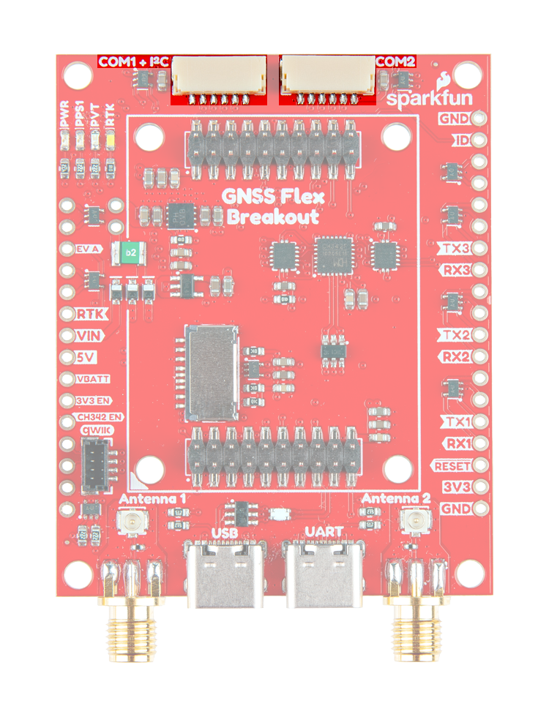
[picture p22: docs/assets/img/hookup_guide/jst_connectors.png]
JST Connectors

<figcaption markdown>The JST connectors on the GNSS Flex Breakout board.</figcaption>
</figure>

</div>

<div markdown>

- <code>COM1 + I^2^C</code>
	- Breaks out the `UART1` and I^2^C interfaces for a connection to a Pixhawk flight controller
	- 5V power output
- `COM2`
	- Breaks out the `UART2` interface *(w/ flow control)* for connection to a [telemetry radio](./hardware_assembly.md#jst-connectors)
	- 5V power output

!!! danger "Power Options"
	By default, the locking JST connectors provide a 5V power output. However, an optional 3.3V power output can be configured by modifying the [jumpers](#jumpers) underneath the connectors, on the opposite side of the board.

	These connector can also function as an optional 5V power input, when all other power sources have been disconnected from the GNSS Flex Breakout board.

</div>

</div>

???+ info "Pin Connections"
	Below, are tables of the pin connections of each JST connector:

	<div class="grid" markdown>

	<article style="text-align: center;" markdown>

	<table border="1" markdown>
	<tr markdown>
	<th align="center" colspan="7" markdown>**<code>COM1 + I^2^C</code>**
	</th>
	</tr>
	<tr markdown>
	<th style="vertical-align:middle;">Pin Number</th>
	<td align="center" markdown>
		**1**<br>
		*(Left Side)*
	</td>
	<td align="center" markdown>**2**</td>
	<td align="center" markdown>**3**</td>
	<td align="center" markdown>**4**</td>
	<td align="center" markdown>**5**</td>
	<td align="center" markdown>
		**6**<br>
		*(Right)*
	</td>
	</tr>
	<tr markdown>
	<th style="vertical-align:middle;">Label</th>
	<td align="center" markdown>`5V`</td>
	<td align="center" markdown>`TXD1`</td>
	<td align="center" markdown>`RXD1`</td>
	<td align="center" markdown>`SCL`</td>
	<td align="center" markdown>`SDA`</td>
	<td align="center" markdown>`GND`</td>
	</tr>
	<tr markdown>
	<th style="vertical-align:middle;">Function</th>
	<td align="center" markdown>Power: **5V**</td>
	<td align="center" markdown>UART - Transmit</td>
	<td align="center" markdown>UART - Receive</td>
	<td align="center" markdown>I^2^C - Clock</td>
	<td align="center" markdown>I^2^C - Data</td>
	<td align="center" markdown>Ground</td>
	</tr>
	</table>

	</article>

	<article style="text-align: center;" markdown>

	<table border="1" markdown>
	<tr markdown>
	<th align="center" colspan="7" markdown>**`COM2`**
	</th>
	</tr>
	<tr markdown>
	<th style="vertical-align:middle;">Pin Number</th>
	<td align="center" markdown>
		**1**<br>
		*(Left Side)*
	</td>
	<td align="center" markdown>**2**</td>
	<td align="center" markdown>**3**</td>
	<td align="center" markdown>**4**</td>
	<td align="center" markdown>**5**</td>
	<td align="center" markdown>
		**6**<br>
		*(Right)*
	</td>
	</tr>
	<tr markdown>
	<th style="vertical-align:middle;">Label</th>
	<td align="center" markdown>`5V`</td>
	<td align="center" markdown>`TXD2`</td>
	<td align="center" markdown>`RXD2`</td>
	<td align="center" markdown>`CTS2`</td>
	<td align="center" markdown>`RTS2`</td>
	<td align="center" markdown>`GND`</td>
	</tr>
	<tr markdown>
	<th style="vertical-align:middle;">Function</th>
	<td align="center" markdown>Power: **5V**</td>
	<td align="center" markdown>Transmit</td>
	<td align="center" markdown>Receive</td>
	<td align="center" markdown>Clear-to-Send</td>
	<td align="center" markdown>Ready-to-Send</td>
	<td align="center" markdown>Ground</td>
	</tr>
	</table>

	</article>

	</div>

## SD Card Slot
Depending on the capabilities of the GNSS receiver, the &micro;SD card slot can be used for data logging.

<figure markdown>
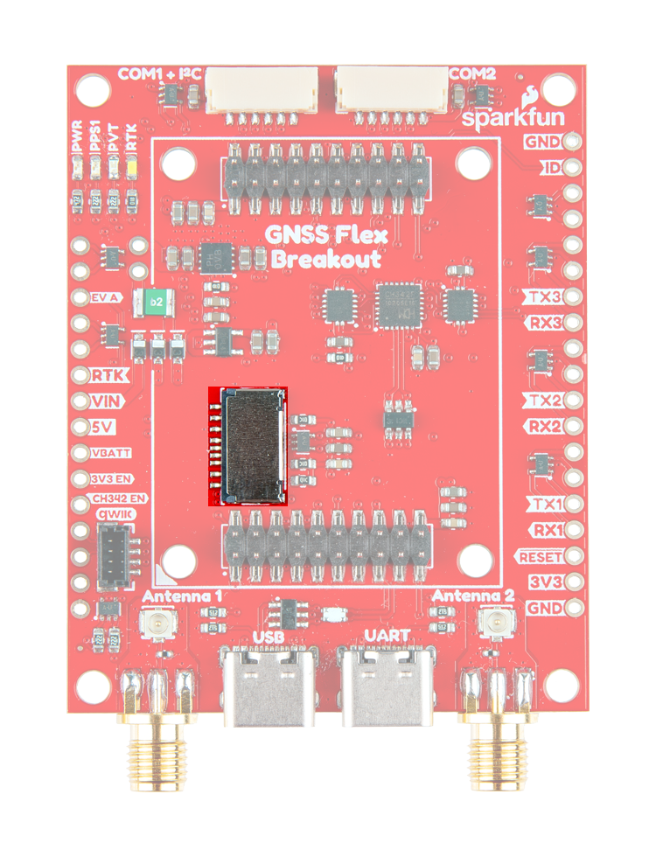
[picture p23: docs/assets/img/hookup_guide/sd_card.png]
SD card slot

<figcaption markdown>The SD card slot on the GNSS Flex Breakout board.</figcaption>
</figure>

## Qwiic Connector
The Qwiic connector is attached to the I^2^C interface of the GNSS Flex headers. Depending on the capabilities of the GNSS Flex module, the I^2^C interface could be used to configure and communicate with the GNSS receiver.

<figure markdown>
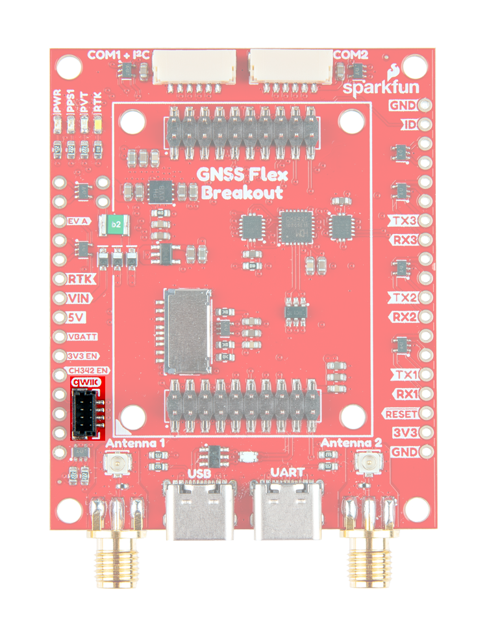
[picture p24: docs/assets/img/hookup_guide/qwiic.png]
Qwiic connector

<figcaption markdown>The Qwiic connector on the GNSS Flex Breakout board.</figcaption>
</figure>

??? tip "What is Qwiic?"

	<div class="grid" markdown>

	<div markdown>

	<!-- Qwiic Banner -->
	<article style="text-align: center;" markdown>
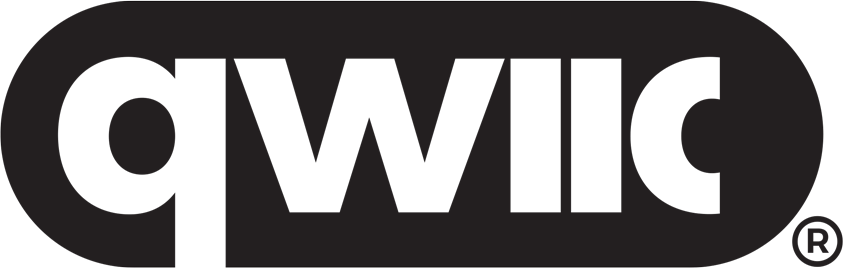
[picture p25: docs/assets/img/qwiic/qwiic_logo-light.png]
Qwiic Logo - light theme (https://www.sparkfun.com/qwiic)
	
	Qwiic Logo - dark theme (https://www.sparkfun.com/qwiic)
	</article>

	---

	The [Qwiic connect system](https://www.sparkfun.com/qwiic) is a solderless, polarized connection system that allows users to seamlessly daisy chain I^2^C boards together. Play the video, to learn more about the Qwiic connect system or click on the banner above to learn more about [Qwiic products](https://www.sparkfun.com/qwiic).

	</div>

	<div style="max-height=400px;" markdown>

	<article class="video-500px" style="text-align: center; margin: auto;" markdown>
	<iframe src="https://www.youtube.com/embed/x0RDEHqFIF8" title="SparkFun's Qwiic Connect System" frameborder="0" allow="accelerometer; encrypted-media; gyroscope; picture-in-picture" allowfullscreen></iframe>
	QR code to instructional video
	</article>

	</div>

	</div>

	!!! info "Features of the Qwiic System"

		=== "No Soldering"

			no soldering - light theme
			no soldering - dark theme

			Qwiic cables (4-pin JST) plug easily from development boards to sensors, shields, accessory boards and more, making easy work of setting up a new prototype.

		=== "Polarized Connector"

			polarized connector - light theme
			polarized connector - dark theme

			There's no need to worry about accidentally swapping the `SDA` and `SCL` wires on your breadboard. The Qwiic connector is polarized so you know you’ll have it wired correctly every time.

			The part numbers for the PCB connector is `SM04B-SRSS` ([Datasheet](https://cdn.sparkfun.com/assets/parts/1/2/2/8/9/Qwiic_Connector_Datasheet.pdf)) and the mating connector on the cables is `SHR04V-S-B`; or an equivalent *1mm pitch, 4-pin JST connection*.

		=== "Daisy Chain-able"

			daisy chainable - light theme
			daisy chainable - dark theme

			It’s time to leverage the power of the I^2^C bus! Most Qwiic boards will have two or more connectors on them, allowing multiple devices to be connected.

## Jumpers
There are twelve jumpers on the GNSS Flex Breakout:

??? note "Never modified a jumper before?"
	Check out our <a href="https://learn.sparkfun.com/tutorials/664">Jumper Pads and PCB Traces tutorial</a> for a quick introduction!

	<div class="grid cards" markdown align="center">

	-   <a href="https://learn.sparkfun.com/tutorials/664">
		<figure markdown>
		Tutorial thumbnail
		</figure>

		---

		**How to Work with Jumper Pads and PCB Traces**</a>

	</div>

<div class="grid" markdown>

<div markdown>

<figure markdown>
Jumpers on the bottoms of the breakout board
<figcaption markdown>Jumpers on the bottom of the GNSS Flex Breakout board.</figcaption>
</figure>

</div>

<div markdown>

The jumpers for the [status LEDs](#leds), can be cut to disable the associated LED.

- `PWR` - Power *(Red)*
- `PPS` - Pulse-Per-Second *(Yellow)*
- `RTK` - RTK *(White)*
- `PVT` - PVT *(Blue)*

`SHLD`
:   These jumpers can be cut to isolate the shielding of the associated [USB-C connector](#usb-connectors) from the ground plane of the board.

`VOUT`
:   These jumpers can be modified to configure the I/O voltage of the [JST connectors](#jst-connectors) between 3.3V or 5V.

`I2C`
:   This jumper, next to the [Qwiic connector](#qwiic-connector), can be bridged to attach 2.2k&ohm; pull-up resistors to the I^2^C bus.

`VBACKUP`
:   This jumper can be disconnected to allow for an external battery to be connected `VBACKUP` [PTH](https://en.wikipedia.org/wiki/Through-hole_technology "Plated Through Holes") pin.

`CH342 EN`
:   This jumper can be shorted, to disable the CH342 USB-to serial converter. This allows the UART interfaces to be accessed from the [PTH](https://en.wikipedia.org/wiki/Through-hole_technology "Plated Through Holes") or JST connections, instead of their USB connection.

`MEAS`
: This jumper can be utilized to measure the current coming into the `5V` power rail from either of the USB and/or `VIN` power sources.

</div>

</div>

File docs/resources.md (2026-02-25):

## Product Resources

- :sfe: Product Page: [SparkFun GNSS Flex Breakout](https://www.sparkfun.com/sparkfun-gnss-flex-breakout.html)
- :material-folder-cog: Design Files:
	- :fontawesome-solid-file-pdf: [Schematic](./assets/board_files/schematic.pdf)
	- :fontawesome-solid-file-pdf: [Board Dimensions](./assets/board_files/dimensions.pdf)
	- :material-folder-zip: [KiCad Files](./assets/board_files/kicad_files.zip)
	- :material-cube-outline: [STEP File](./assets/3d_model/cad_model.step)
- Component Documentation
	- :fontawesome-solid-file-pdf: [CH342 Datasheet](./assets/component_documentation/CH342%20Datasheet.pdf)
	- :fontawesome-solid-file-pdf: [RT9080 Datasheet](./assets/component_documentation/RT9080.pdf)
	- :fontawesome-solid-file-pdf: [AP7361C Datasheet](./assets/component_documentation/AP7361C.pdf)
	- :fontawesome-solid-file-pdf: [JST-GH Datasheet](./assets/component_documentation/JST-GH_datasheet.pdf)
	- :fontawesome-solid-file-pdf: [JST-SH Datasheet](./assets/component_documentation/JST-SH_datasheet.pdf)
- :material-github: [Hardware Repo](https://github.com/sparkfun/SparkFun_GNSS_Flex_Breakout)

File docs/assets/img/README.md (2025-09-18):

img directory
====================
This folder should contain the images for the product documentation

## General Images
- `sfe-logo.png` - SparkFun flame logo (favicon)

## Directory
- `graphical_datasheet` - Files for graphical datasheet
- `hookup_guide` - Images for the hookup guide pages
- `qr_code` - QR code images
- `qwiic` - Images for Qwiic Banner

## QR Codes
- [QR code generator](https://qrgenerator.org/)
	- Flame Color: #E0311D
	- Frame Color: #3C464D
- [Remove meta data from svg](https://jakearchibald.github.io/svgomg/)

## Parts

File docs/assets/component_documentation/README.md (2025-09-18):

SparkFun Documentation
=======================

This directory should include any necessary datasheets, example number crunching, etc.

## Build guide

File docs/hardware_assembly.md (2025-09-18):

## External Antenna
In order to receive [GNSS](https://en.wikipedia.org/wiki/Satellite_navigation "Global Navigation Satellite System") signals, users will need a compatible antenna. For the best performance, we recommend an active L1/L2/L5/L6/L-band GNSS antenna for most of our GNSS Flex modules.

<figure markdown>
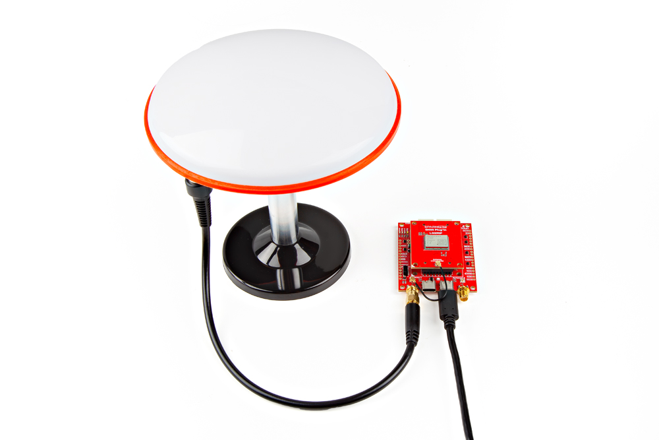
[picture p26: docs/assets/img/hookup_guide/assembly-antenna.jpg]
Antenna connection

<figcaption markdown>Connecting an antenna to the GNSS Flex Breakout board.</figcaption>
</figure>

!!! tip
	For the best performance, we recommend users choose a compatible L1/L2/L5/L6 GNSS antenna and utilize a low-loss cable. Also, don't forget that GNSS signals are fairly weak and can't penetrate buildings or dense vegetation. The GNSS antenna should have an unobstructed view of the sky.

	!!! note
		Please keep in mind that these are general suggestions for our GNSS Flex modules. Some of these boards may have multiple GNSS antenna connections, an integrated antenna, support specific frequency bands, etc. For more details on a specific GNSS Flex module, please refer to their [hookup guide](../modules.md).

!!! note "Direct Mounts"
	For users that want to attach a [helical](https://www.sparkfun.com/gnss-multi-band-l1-l2-l5-helical-antenna-sma.html) or similar GNSS antenna directly to the board, the antenna will block at least one of the USB-C connectors. Additionally, users should also consider the clearance to the USB-C connectors from the bottom of the antenna.

### Connection Options
There are two options for connecting an external antenna to a GNSS Flex module:

- An external antenna can be connected through the U.FL connector on the GNSS Flex board.
- However, for a sturdier connection, there is a signal pass-through between each pair of U.FL and SMA antenna connectors on the GNSS Flex Breakout board. To utilize the SMA connector, users can bridge the U.FL connections between the boards with a U.FL cable.

<div class="grid" markdown>

<div markdown>

<figure markdown>
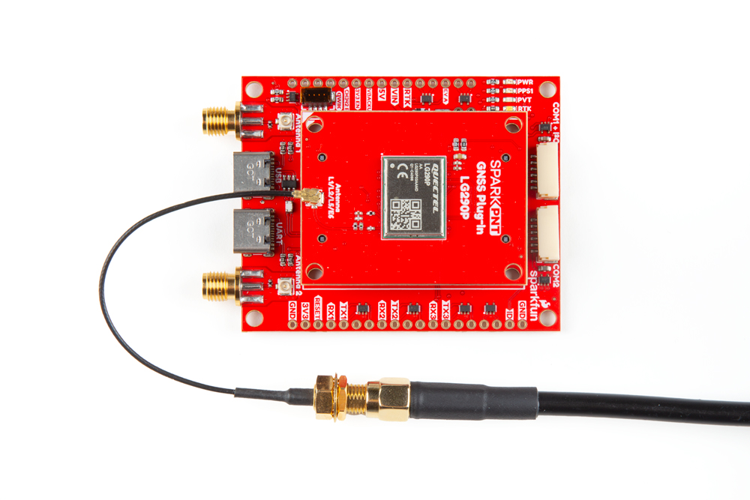
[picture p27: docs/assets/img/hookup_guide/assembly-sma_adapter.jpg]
Antenna connection with SMA adapter

<figcaption markdown>Attaching an antenna directly to the GNSS Flex module with an adapter cable.</figcaption>
</figure>

</div>

<div markdown>

<figure markdown>
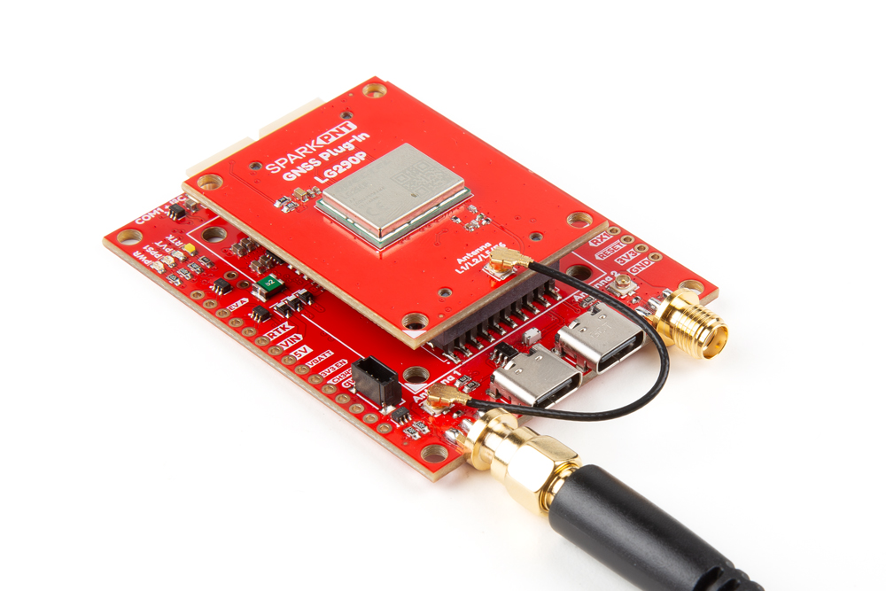
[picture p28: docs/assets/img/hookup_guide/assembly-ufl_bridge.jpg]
Antenna connection to the breakout board

<figcaption markdown>Bridging the U.FL connectors on the boards, to utilize the SMA connector on the GNSS Flex Breakout board.</figcaption>
</figure>

</div>

</div>

### Signal Bridge
The signal bridges on the GNSS Flex Breakout can be utilized to connect an external antenna to the SMA connectors. For the connection to work, an U.FL cable needs to bridge the antenna connection from the GNSS Flex module to the GNSS Flex Breakout board. Due to the space constraint, we recommend connecting the U.FL cable to the GNSS Flex Breakout before attaching the GNSS Flex module to the breakout board.

<div class="grid" markdown>

<div markdown>

<figure markdown>
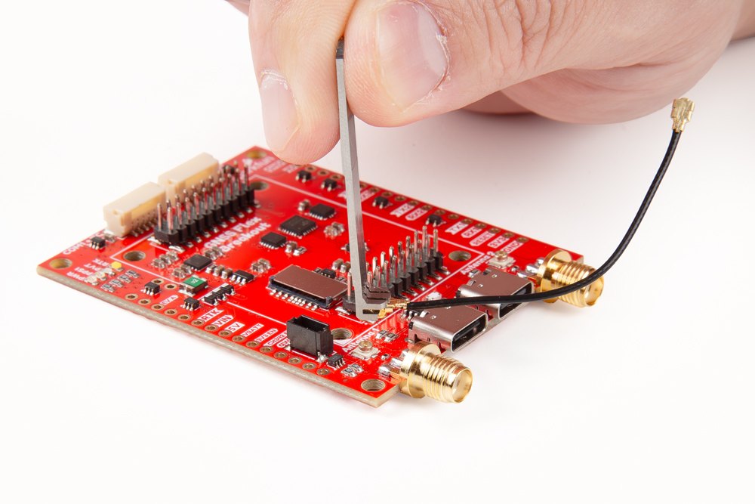
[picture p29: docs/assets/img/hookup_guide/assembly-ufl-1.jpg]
U.FL cable attached to breakout board

<figcaption markdown>Step 1 - Connect the U.FL cable to the GNSS Flex Breakout board.</figcaption>
</figure>

</div>

<div markdown>

<figure markdown>
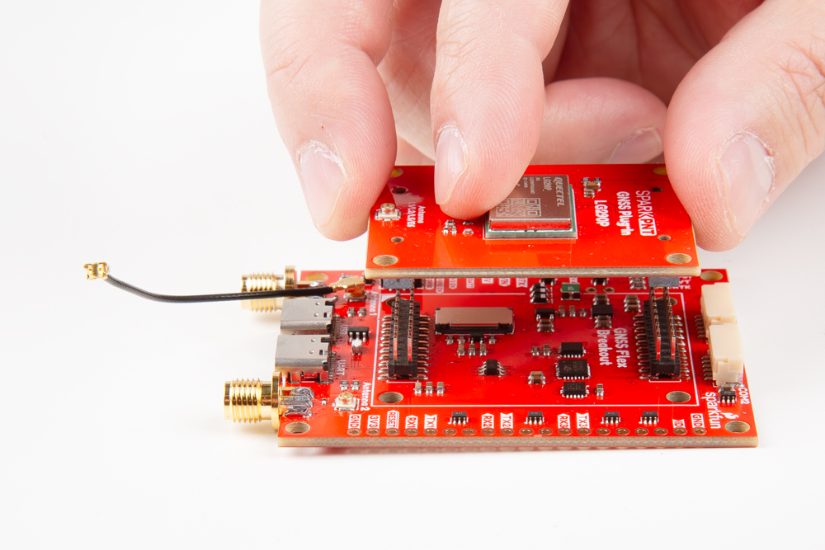
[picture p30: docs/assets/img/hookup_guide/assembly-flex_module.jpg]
Attaching GNSS Flex module to breakout board

<figcaption markdown>Step 2 - Attach the GNSS Flex module to the breakout board.</figcaption>
</figure>

</div>

<div markdown>

<figure markdown>
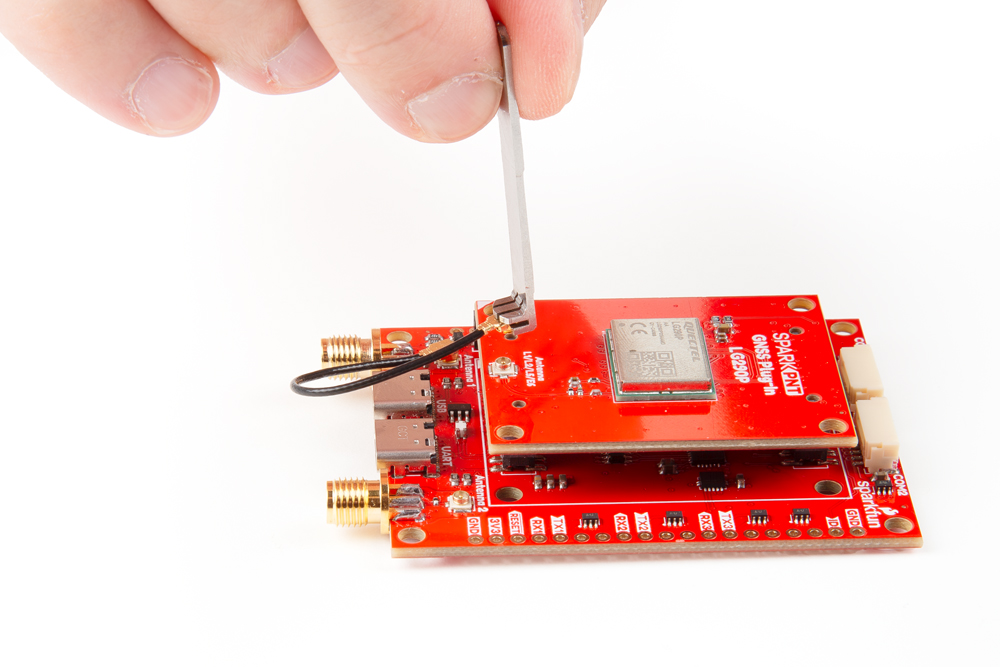
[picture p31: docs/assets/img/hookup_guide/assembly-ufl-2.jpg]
U.FL cable attached to GNSS Flex module

<figcaption markdown>Step 3 - Connect the other end of the U.FL cable to the GNSS Flex module.</figcaption>
</figure>

</div>

<div markdown>

<figure markdown>
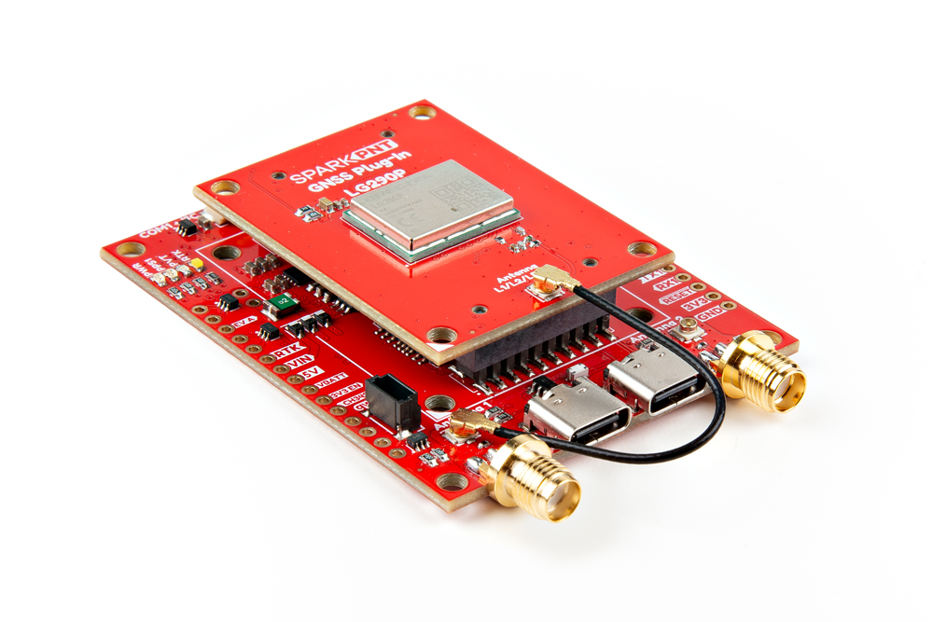
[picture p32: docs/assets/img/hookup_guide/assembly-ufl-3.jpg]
Antenna connection bridged

<figcaption markdown>A U.FL cable bridging the antenna connection between the boards.</figcaption>
</figure>

</div>

</div>

## Attach Module
The GNSS Flex system is a modular ecosystem designed around two 2x10-pin, 2mm pitch headers, so boards are pin-compatible for upgrades and easily swapped for repairs. Users simply, stack a SparkPNT GNSS Flex module onto the headers of its associated *carrier* board.

!!! tip "SMA Connector"
	When bridging the antenna connection to the SMA connector of the GNSS Flex Breakout, we recommend attaching the U.FL cable to the breakout board before the GNSS Flex module.

<figure markdown>
Attaching GNSS Flex module to breakout board
<figcaption markdown>Attaching a GNSS FLex module to the GNSS Flex Breakout board.</figcaption>
</figure>

### Board Alignment
The alignment indicator for mating these boards, is annotated with a triangle in the corner of the mating area.

<figure markdown>
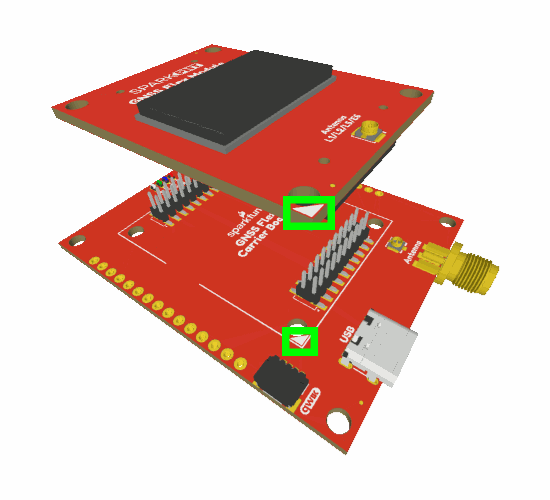
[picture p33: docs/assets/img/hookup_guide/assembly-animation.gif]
Flex system board mating

<figcaption markdown>The alignment and connection of a SparkPNT GNSS Flex module on top of a *carrier* board.</figcaption>
</figure>

## USB Connectors
The USB connections are primarily utilized to power and communicate with a SparkPNT GNSS Flex module. Users only need to connect the GNSS Flex breakout board to a computer using a USB-C cable.

<div class="grid" markdown>

<div markdown>

### USB Interface
If the GNSS Flex module has the capability, a USB-C connector is provided on the GNSS Flex Breakout for the USB interface of the GNSS receiver.

<figure markdown>
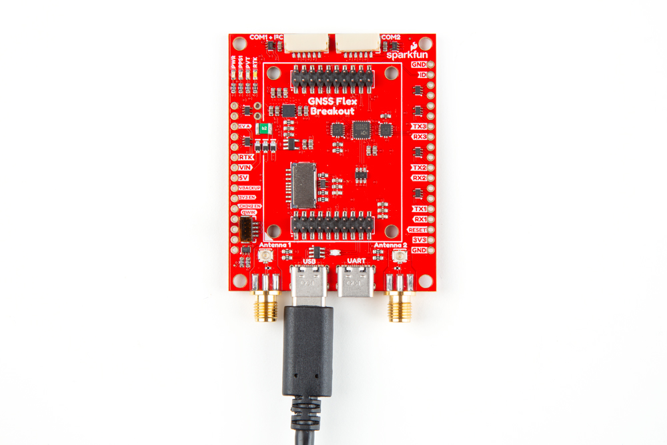
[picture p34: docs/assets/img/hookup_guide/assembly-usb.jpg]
USB connection - USB

<figcaption markdown>Connecting to the USB interface of the GNSS Flex module to a computer.</figcaption>
</figure>

</div>

<div markdown>

### UART Interface
A USB-C connector is provided on the GNSS Flex Breakout for the `UART1` and `UART2` interfaces of the GNSS receiver.

<figure markdown>
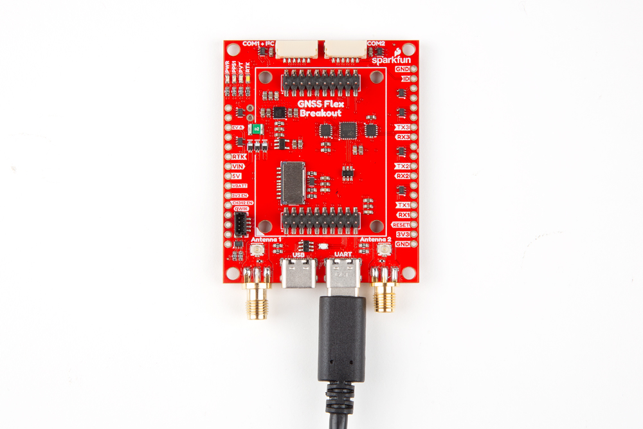
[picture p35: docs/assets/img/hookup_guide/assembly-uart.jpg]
USB connection - UART

<figcaption markdown>Connecting to the UART interfaces of the GNSS Flex module to a computer.</figcaption>
</figure>

!!! tip "USB Driver"
	Users may need to install the [USB driver](./software_overview.md#ch342-usb-driver) for the CH342 USB-to-serial converter chip.

</div>

</div>

## Breakout Pins
The [PTH](https://en.wikipedia.org/wiki/Through-hole_technology "Plated Through Holes") pins on the GNSS Flex breakout board are broken out into 0.1"-spaced pins on the outer edges of the board. For a more permanent connection, users can solder wires directly to the board. Otherwise, headers are a great option for their flexibility to develop with. When selecting headers, be sure you are aware of the functionality you require.

<div class="grid" markdown>

<div markdown>

<figure markdown>
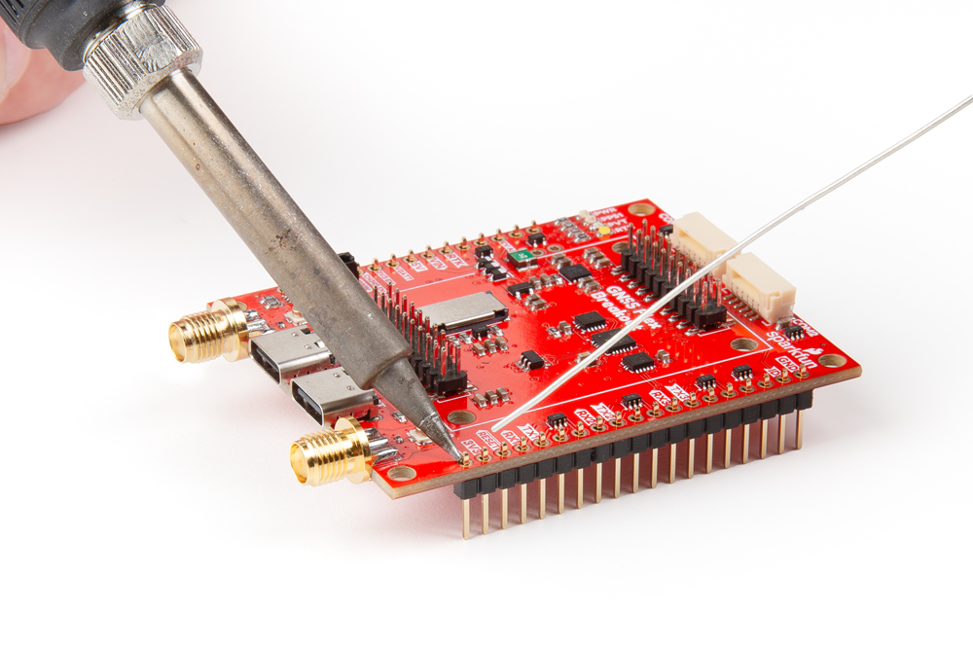
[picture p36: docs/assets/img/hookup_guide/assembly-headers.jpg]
Soldering headers

<figcaption markdown>Soldering headers to the GNSS Flex breakout board.</figcaption>
</figure>

</div>

<div markdown>

!!! note "New to soldering?"
	If you have never soldered before or need a quick refresher, check out our [How to Solder: Through-Hole Soldering](https://learn.sparkfun.com/tutorials/how-to-solder-through-hole-soldering) guide.

	<div class="grid cards" markdown align="center">

	-   <a href="https://learn.sparkfun.com/tutorials/5">
		<figure markdown>
		Tutorial thumbnail
		</figure>

		---

		**How to Solder: Through-Hole Soldering**</a>

	</div>

</div>

</div>

## JST Connectors
There are two locking JST connectors to easily access the UART and I^2^C interfaces of the GNSS Flex headers. Depending on the capabilities of the GNSS Flex module, the UART and I^2^C interfaces could be used to configure and communicate with the GNSS receiver. For example, the `COM1` JST connector can be used to attach a PixHawk flight controller.

<div class="grid" markdown>

<figure markdown>
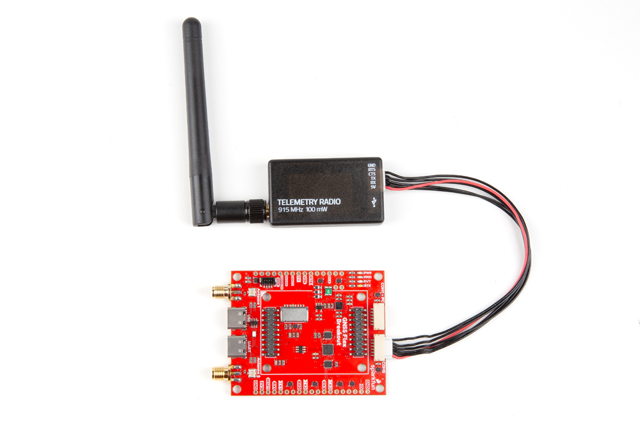
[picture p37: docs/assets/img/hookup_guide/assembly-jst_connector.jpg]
JST connection

<figcaption markdown>Attaching a [telemetry radio](https://www.sparkfun.com/sik-telemetry-radio-v3-915mhz-100mw.html) to the `COM2` JST connector of the GNSS Flex Breakout board for RTK corrections.</figcaption>
</figure>

<div markdown>

!!! tip "Output Voltage"
	In addition, each JST connector has a [`VOUT` jumper](./hardware_overview.md#jumpers) that users can modify to change the output voltage to 3.3V.

??? note "Never modified a jumper before?"
	Check out our <a href="https://learn.sparkfun.com/tutorials/664">Jumper Pads and PCB Traces tutorial</a> for a quick introduction!

	<article class="grid cards" style="text-align: center;" markdown>

	-   <a href="https://learn.sparkfun.com/tutorials/664">
		<figure markdown>
		Tutorial thumbnail
		</figure>

		---

		**How to Work with Jumper Pads and PCB Traces**</a>

	</article>

</div>

</div>

When connecting the GNSS Flex Breakout board to another device, users need to be aware of the pin connections and voltage ranges of the products. Below, are tables of the pin connections for each JST connector that users can reference.

<div class="grid" markdown>

<article style="text-align: center;" markdown>

<table border="1" markdown>
<tr markdown>
<th align="center" colspan="7" markdown>**<code>COM1 + I^2^C</code>**
</th>
</tr>
<tr markdown>
<th style="vertical-align:middle;">Pin Number</th>
<td align="center" markdown>
	**1**<br>
	*(Left Side)*
</td>
<td align="center" markdown>**2**</td>
<td align="center" markdown>**3**</td>
<td align="center" markdown>**4**</td>
<td align="center" markdown>**5**</td>
<td align="center" markdown>
	**6**<br>
	*(Right)*
</td>
</tr>
<tr markdown>
<th style="vertical-align:middle;">Label</th>
<td align="center" markdown>`5V`</td>
<td align="center" markdown>`TXD1`</td>
<td align="center" markdown>`RXD1`</td>
<td align="center" markdown>`SCL`</td>
<td align="center" markdown>`SDA`</td>
<td align="center" markdown>`GND`</td>
</tr>
<tr markdown>
<th style="vertical-align:middle;">Function</th>
<td align="center" markdown>Power: **5V**</td>
<td align="center" markdown>UART - Transmit</td>
<td align="center" markdown>UART - Receive</td>
<td align="center" markdown>I^2^C - Clock</td>
<td align="center" markdown>I^2^C - Data</td>
<td align="center" markdown>Ground</td>
</tr>
</table>

</article>

<article style="text-align: center;" markdown>

<table border="1" markdown>
<tr markdown>
<th align="center" colspan="7" markdown>**`COM2`**
</th>
</tr>
<tr markdown>
<th style="vertical-align:middle;">Pin Number</th>
<td align="center" markdown>
	**1**<br>
	*(Left Side)*
</td>
<td align="center" markdown>**2**</td>
<td align="center" markdown>**3**</td>
<td align="center" markdown>**4**</td>
<td align="center" markdown>**5**</td>
<td align="center" markdown>
	**6**<br>
	*(Right)*
</td>
</tr>
<tr markdown>
<th style="vertical-align:middle;">Label</th>
<td align="center" markdown>`5V`</td>
<td align="center" markdown>`TXD2`</td>
<td align="center" markdown>`RXD2`</td>
<td align="center" markdown>`CTS2`</td>
<td align="center" markdown>`RTS2`</td>
<td align="center" markdown>`GND`</td>
</tr>
<tr markdown>
<th style="vertical-align:middle;">Function</th>
<td align="center" markdown>Power: **5V**</td>
<td align="center" markdown>Transmit</td>
<td align="center" markdown>Receive</td>
<td align="center" markdown>Clear-to-Send</td>
<td align="center" markdown>Ready-to-Send</td>
<td align="center" markdown>Ground</td>
</tr>
</table>

</article>

</div>

## SD Card Slot
If the GNSS Flex module has the capability, an SD card slot is provided on the GNSS Flex Breakout for data logging.

<figure markdown>
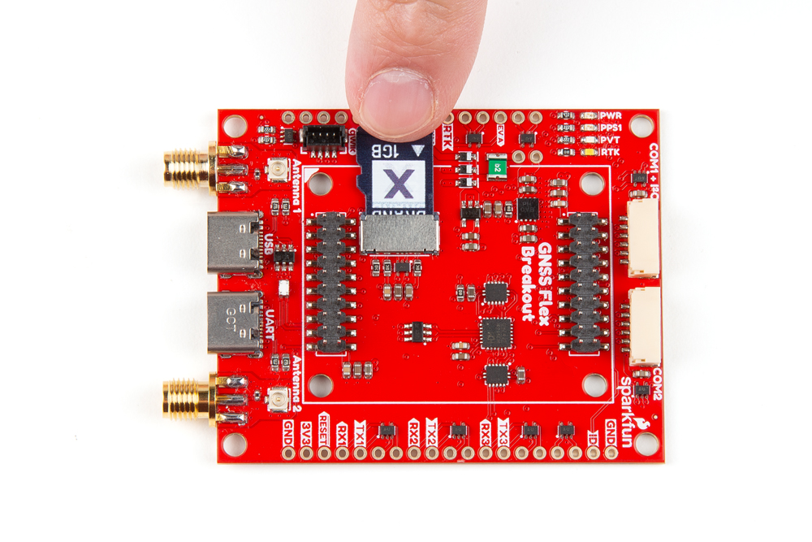
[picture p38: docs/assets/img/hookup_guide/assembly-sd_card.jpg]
SD card slot

<figcaption markdown>Inserting an &micro;SD card to the SD card slot on the GNSS Flex Breakout board.</figcaption>
</figure>

## Qwiic Devices
The Qwiic system allows users to effortlessly prototype with a Qwiic compatible I^2^C device without soldering. Users can attach GNSS Flex breakout board along with other Qwiic [sensors or boards](https://www.sparkfun.com/special-categories/qwiic.html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) to any [Qwiic compatible microcontroller](https://www.sparkfun.com/development-boards/microcontrollers.html?sf_global_qwiic_connector=8262), with just a few [Qwiic cables](https://www.sparkfun.com/sparkfun-qwiic-cable-kit.html). *(The example below, is for demonstration purposes and is not pertinent to the board functionality or this tutorial.)*

<figure markdown>
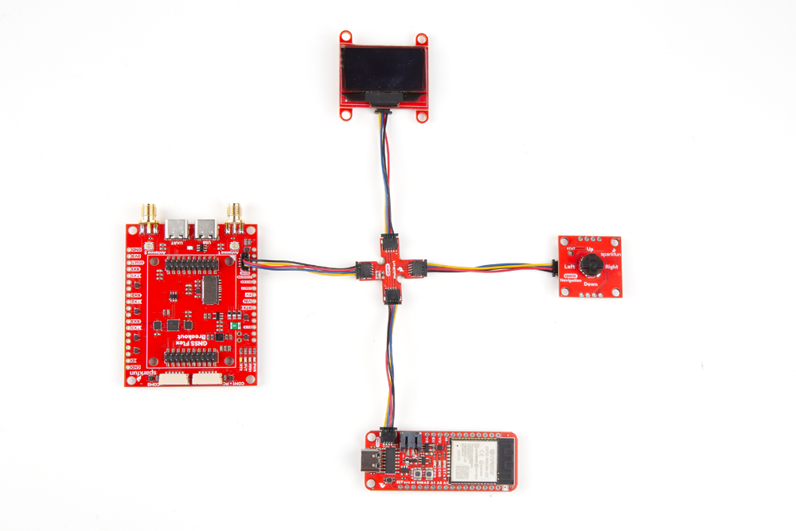
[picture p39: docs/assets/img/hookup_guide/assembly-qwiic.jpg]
Qwiic devices connected

<figcaption markdown>Several Qwiic devices and microcontroller connected to the GNSS Flex breakout board.</figcaption>
</figure>

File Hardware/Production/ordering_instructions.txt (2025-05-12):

Ordering Instructions:
Panel dimensions: 156.44 x 115.80 mm.
Controlled Impedance: JLC04161H-7628
Material: TG135
Solder Mask: Red
Silkscreen Color: White
Layers: 4
Finish: ENIG
Thickness: 1.6mm
Inner Copper Weight: 0.5oz
Outer Copper Weight: 1oz
Minimum track width: 0.18mm (7.00mil)
Minimum via drill: 0.30mm (12.00mil)
No Clean Process

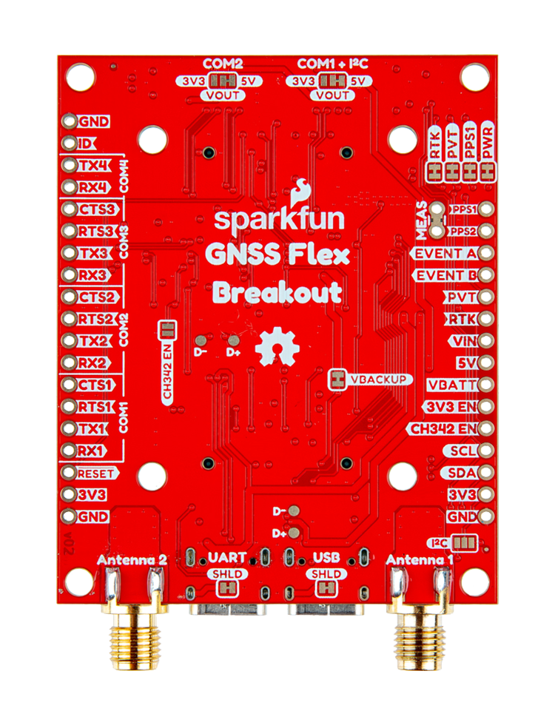
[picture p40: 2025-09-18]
docs/assets/img/hookup_guide/bottom-template.png

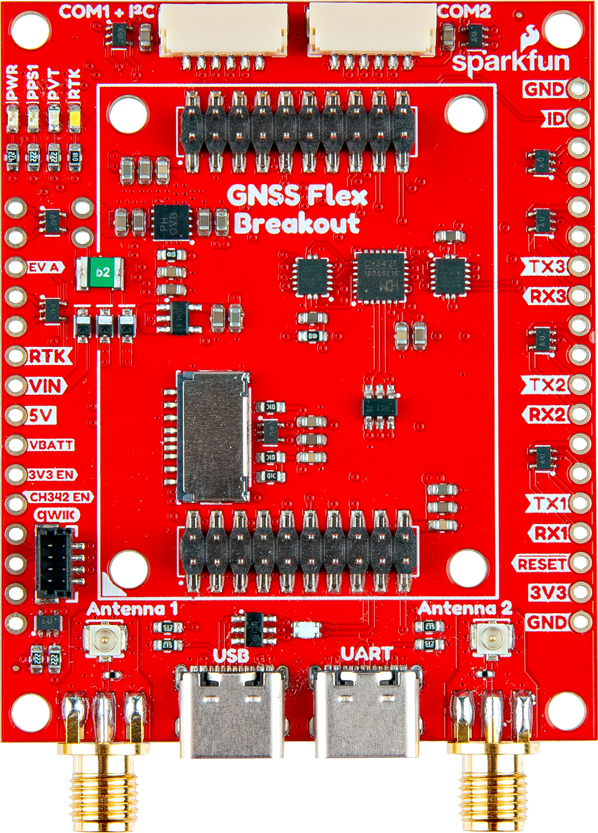
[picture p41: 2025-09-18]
docs/assets/img/hookup_guide/top.png

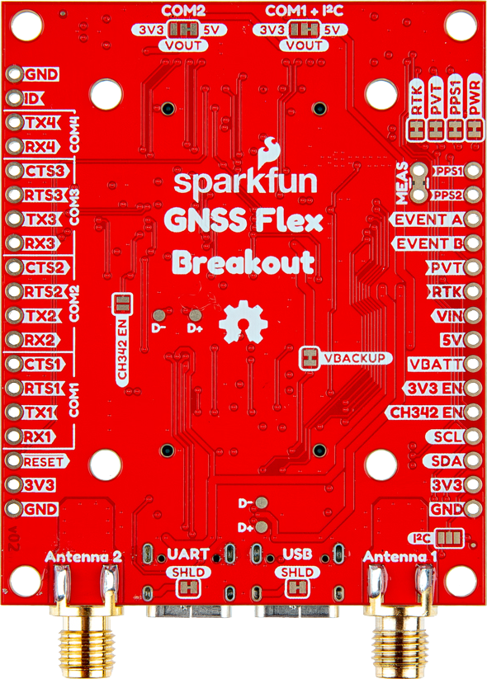
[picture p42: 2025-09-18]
docs/assets/img/hookup_guide/bottom.png

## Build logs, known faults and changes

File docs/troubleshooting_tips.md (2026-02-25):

!!! warning "Need Help?"
	If you need technical assistance or more information on a product that is not working as you expected, we recommend heading on over to the [SparkFun Forums](https://community.sparkfun.com).

	!!! info "Account Registration Required"
		If this is your first visit to our forum, you'll need to create a [Forum Account](https://community.sparkfun.com/signup) to post questions.

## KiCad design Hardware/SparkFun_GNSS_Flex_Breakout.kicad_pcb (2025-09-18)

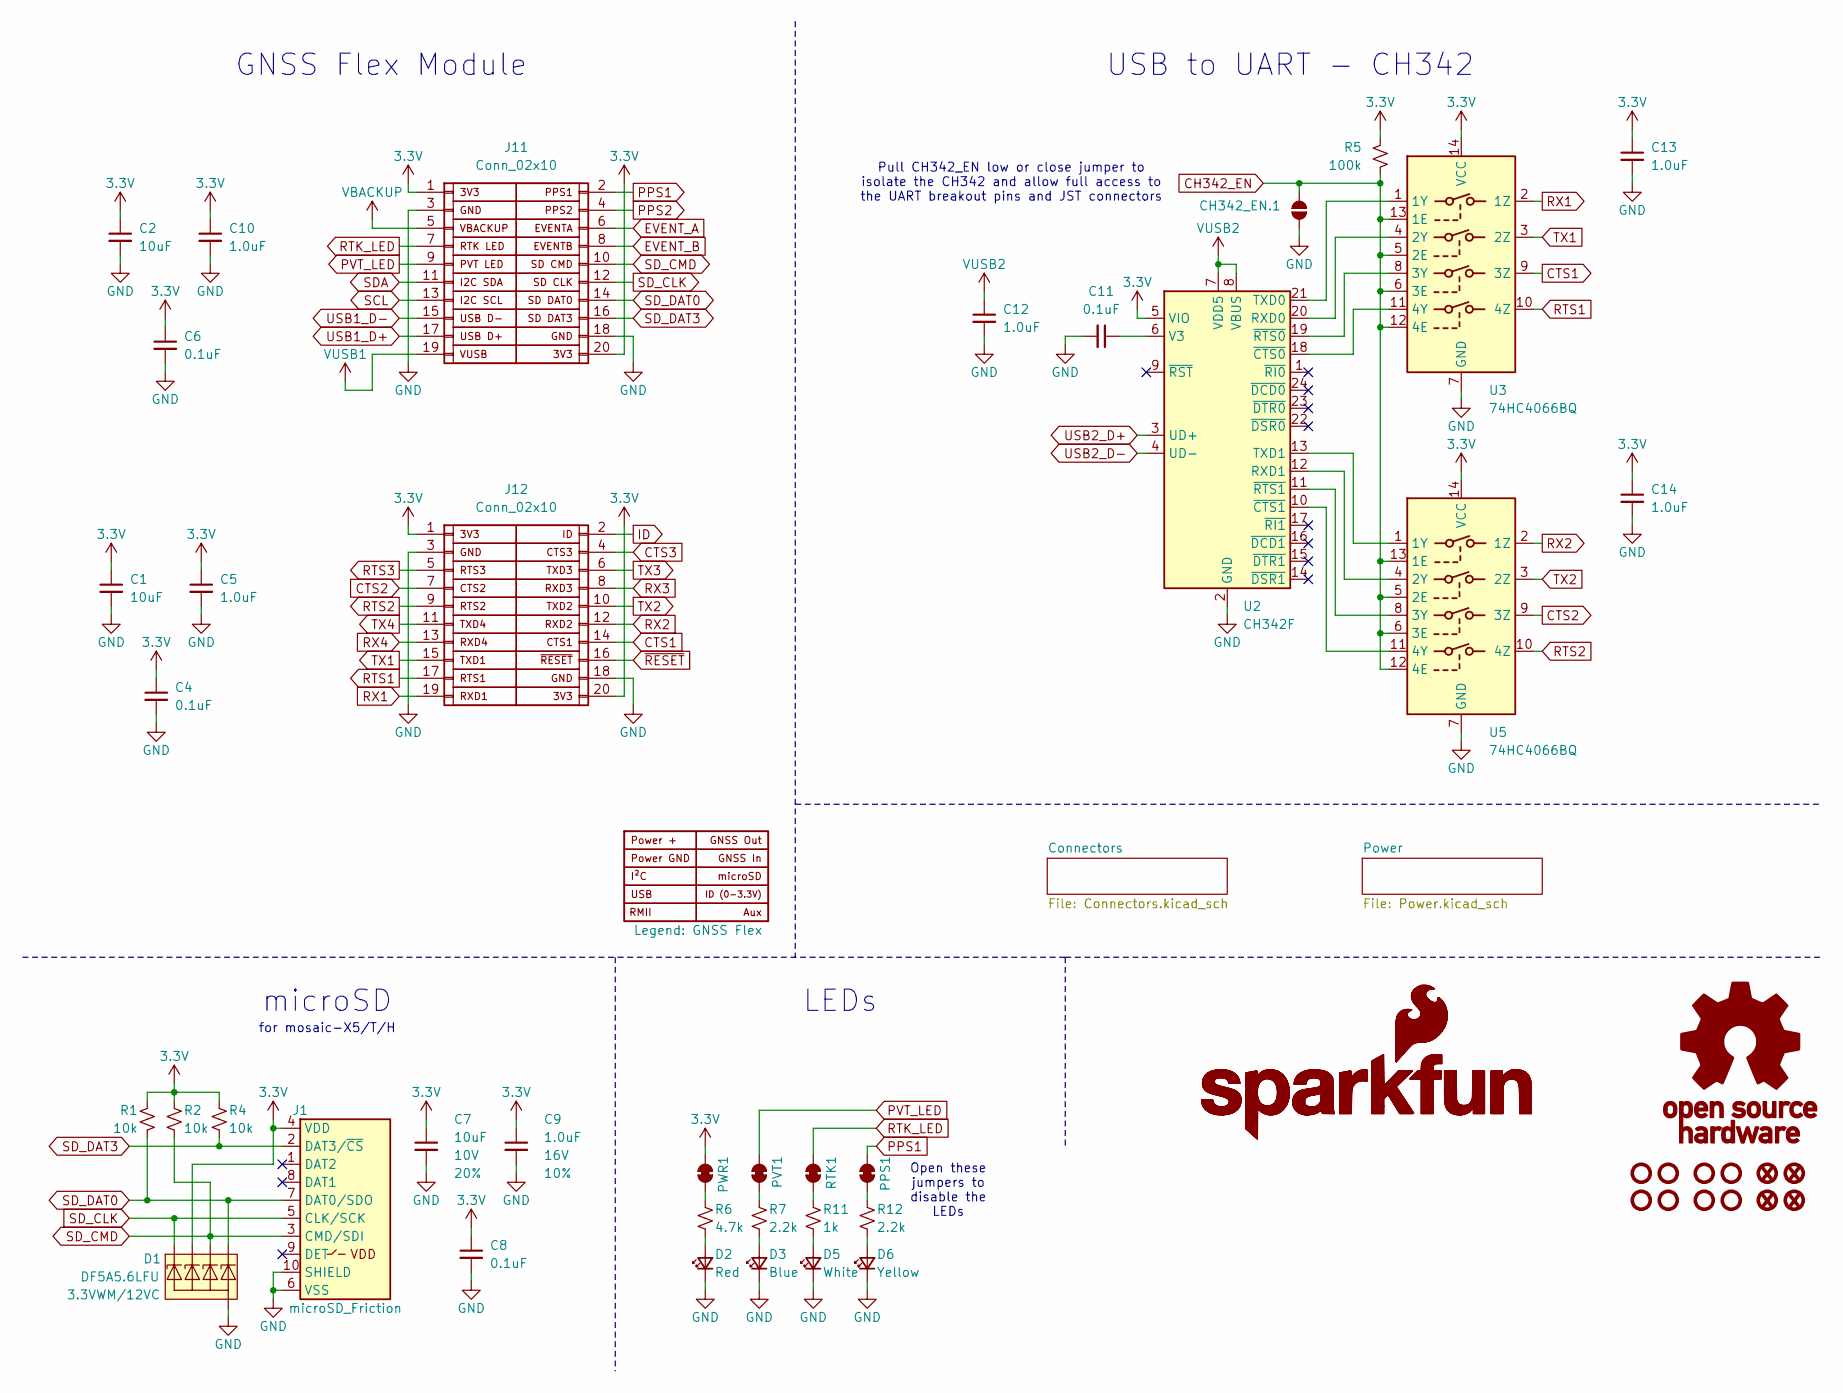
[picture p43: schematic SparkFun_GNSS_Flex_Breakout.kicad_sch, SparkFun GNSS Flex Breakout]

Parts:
C1, C2, C7: 10uF; C_0603_1608Metric; Voltage 10V; Tolerance 20%
C4, C6, C8, C11: 0.1uF; C_0603_1608Metric; Voltage 25V; Tolerance 20%
C5, C9, C10, C12, C13, C14: 1.0uF; C_0603_1608Metric; Voltage 16V; Tolerance 10%
CH342_EN.1: Jumper_2_NO
D1: DF5A5.6LFU; SOT-353; Rating 3.3VWM/12VC
D2: Red; LED_0603_1608Metric_Red
D3: Blue; LED_0603_1608Metric_Blue
D5: White; LED_0603_1608Metric_White
D6: Yellow; LED_0603_1608Metric_Yellow
FID1, FID2, FID3, FID4: Fiducial_0.5mm; Fiducial_0.5mm_Mask1mm
G1, G2: SparkFun_Logo
G3: OSHW_Logo; Creative_Commons_License
J1: microSD_Friction; microSD_Friction_Fit_Common
J11, J12: Conn_02x10; 2x10_2.0mm_Male_Pins_Vertical_SMD_Pegs
J15: Legend: GNSS Flex; GNSS_Flex_Template
PPS1: Jumper_2_NC_Trace
PVT1: Jumper_2_NC_Trace
PWR1: Jumper_2_NC_Trace
R1, R2, R4: 10k; R_0603_1608Metric
R5: 100k; R_0603_1608Metric
R6: 4.7k; R_0603_1608Metric
R7, R12: 2.2k; R_0603_1608Metric
R11: 1k; R_0603_1608Metric
RTK1: Jumper_2_NC_Trace
ST1, ST2, ST3, ST4, ST5, ST6, ST7, ST8: Standoff
U2: CH342F; QFN-24-1EP_4x4mm_P0.5mm_EP2.7x2.7mm
U3, U5: 74HC4066BQ; QFN-14_2.5x3mm_P0.5mm_EP1x1.5mm

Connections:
3.3V: C1.1, C2.1, C4.1, C5.1, C6.1, C7.1, C8.1, C9.1, C10.1, C13.1, C14.1, D1.3 (K2), J1.4 (VDD), J11.1, J11.20, J12.1, J12.20, PWR1.2 (B), R1.2, R2.2, R4.2, R5.2, U2.5 (VIO), U3.14 (VCC), U5.14 (VCC); also elsewhere on the board
CH342_EN: CH342_EN.1.2 (B), R5.1, U3.5 (2E), U3.6 (3E), U3.12 (4E), U3.13 (1E), U5.5 (2E), U5.6 (3E), U5.12 (4E), U5.13 (1E); also elsewhere on the board
CTS1: J12.14, U3.9 (3Z); also elsewhere on the board
CTS2: J12.7, U5.9 (3Z); also elsewhere on the board
CTS3: J12.4; also elsewhere on the board
EVENT_A: J11.6; also elsewhere on the board
EVENT_B: J11.8; also elsewhere on the board
GND: C1.2, C2.2, C4.2, C5.2, C6.2, C7.2, C8.2, C9.2, C10.2, C11.2, C12.2, C13.2, C14.2, CH342_EN.1.1 (A), D1.2 (A), D2.1 (K), D3.1 (K), D5.1 (K), D6.1 (K), J1.6 (VSS), J1.10 (SHIELD), J11.3, J11.18, J12.3, J12.18, U2.2 (GND), U2.25 (GND), U3.7 (GND), U5.7 (GND); also elsewhere on the board
ID: J12.2; also elsewhere on the board
unnamed: D2.2 (A), R6.1
unnamed: D3.2 (A), R7.1
unnamed: D5.2 (A), R11.1
unnamed: D6.2 (A), R12.1
unnamed: PPS1.1 (A), R12.2
unnamed: PVT1.1 (A), R7.2
unnamed: PWR1.1 (A), R6.2
unnamed: R11.2, RTK1.1 (A)
unnamed: U2.20 (RXD0), U3.4 (2Y)
unnamed: U2.12 (RXD1), U5.4 (2Y)
unnamed: U2.21 (TXD0), U3.1 (1Y)
unnamed: U2.13 (TXD1), U5.1 (1Y)
unnamed: C11.1, U2.6 (V3)
unnamed: U2.18 (~CTS0), U3.11 (4Y)
unnamed: U2.10 (~CTS1), U5.11 (4Y)
unnamed: U2.19 (~RTS0), U3.8 (3Y)
unnamed: U2.11 (~RTS1), U5.8 (3Y)
PPS1: J11.2, PPS1.2 (B); also elsewhere on the board
PPS2: J11.4; also elsewhere on the board
PVT_LED: J11.9, PVT1.2 (B); also elsewhere on the board
RTK_LED: J11.7, RTK1.2 (B); also elsewhere on the board
RTS1: J12.17, U3.10 (4Z); also elsewhere on the board
RTS2: J12.9, U5.10 (4Z); also elsewhere on the board
RTS3: J12.5; also elsewhere on the board
RX1: J12.19, U3.2 (1Z); also elsewhere on the board
RX2: J12.12, U5.2 (1Z); also elsewhere on the board
RX3: J12.8; also elsewhere on the board
RX4: J12.13; also elsewhere on the board
SCL: J11.13; also elsewhere on the board
SDA: J11.11; also elsewhere on the board
SD_CLK: D1.1 (K1), J1.5 (CLK/SCK), J11.12
SD_CMD: D1.4 (K3), J1.3 (CMD/SDI), J11.10, R2.1
SD_DAT0: D1.5 (K4), J1.7 (DAT0/SDO), J11.14, R1.1
SD_DAT3: J1.2 (DAT3/~CS), J11.16, R4.1
TX1: J12.15, U3.3 (2Z); also elsewhere on the board
TX2: J12.10, U5.3 (2Z); also elsewhere on the board
TX3: J12.6; also elsewhere on the board
TX4: J12.11; also elsewhere on the board
USB1_D+: J11.17; also elsewhere on the board
USB1_D-: J11.15; also elsewhere on the board
USB2_D+: U2.3 (UD+); also elsewhere on the board
USB2_D-: U2.4 (UD-); also elsewhere on the board
VBACKUP: J11.5; also elsewhere on the board
VUSB1: J11.19; also elsewhere on the board
VUSB2: C12.1, U2.7 (VDD5), U2.8 (VBUS); also elsewhere on the board
~RESET: J12.16; also elsewhere on the board

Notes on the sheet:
LEDs
USB to UART - CH342
GNSS Flex Module
for mosaic-X5/T/H
Open these jumpers to disable the LEDs
microSD
Pull CH342_EN low or close jumper to isolate the CH342 and allow full access to the UART breakout pins and JST connectors

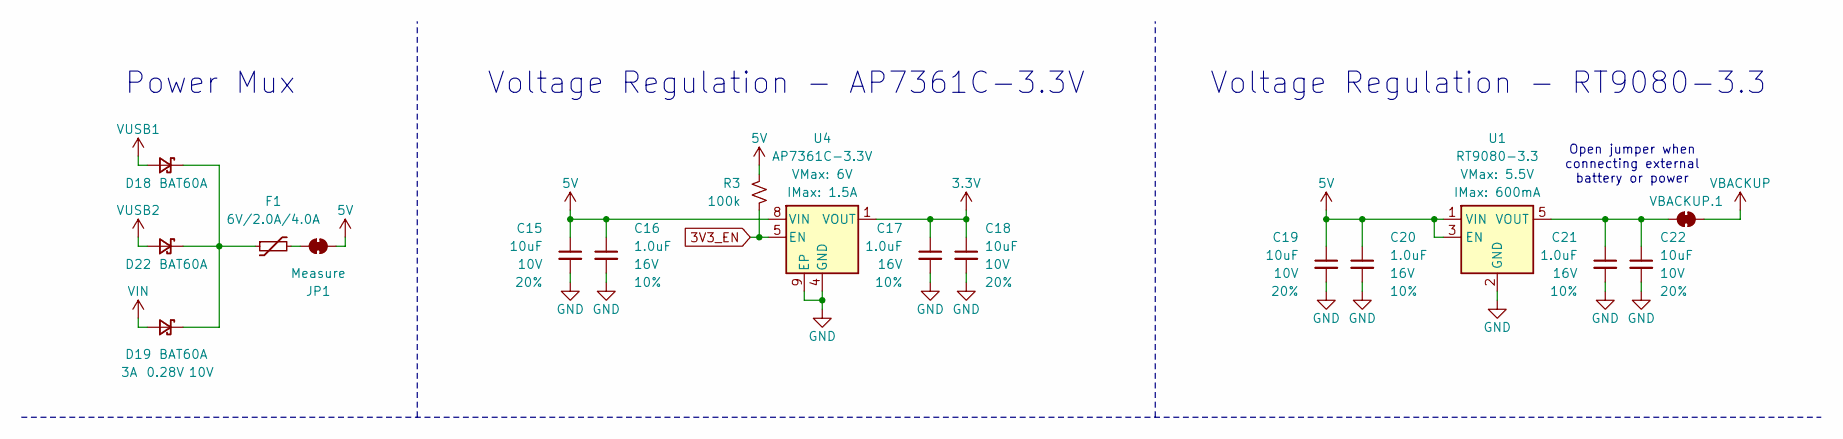
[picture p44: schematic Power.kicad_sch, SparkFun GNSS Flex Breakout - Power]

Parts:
C15, C18, C19, C22: 10uF; C_0603_1608Metric; Voltage 10V; Tolerance 20%
C16, C17, C20, C21: 1.0uF; C_0603_1608Metric; Voltage 16V; Tolerance 10%
D18, D19, D22: BAT60A; SOD-323
F1: 6V/2.0A/4.0A; 1210
JP1: Measure; Jumper_2_PTH_SMD_Combo-NC
R3: 100k; R_0603_1608Metric
U1: RT9080-3.3; SOT23-5
U4: AP7361C-3.3V; DFN-8_3x3mm_P0.65mm_EP2.25x1.5mm
VBACKUP.1: Jumper_2_NC_Trace

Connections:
3.3V: C17.1, C18.1, U4.1 (VOUT); also elsewhere on the board
3V3_EN: R3.1, U4.5 (EN); also elsewhere on the board
5V: C15.1, C16.1, C19.1, C20.1, JP1.2 (B), R3.2, U1.1 (VIN), U1.3 (EN), U4.8 (VIN); also elsewhere on the board
GND: C15.2, C16.2, C17.2, C18.2, C19.2, C20.2, C21.2, C22.2, U1.2 (GND), U4.4 (GND), U4.9 (EP); also elsewhere on the board
unnamed: D18.1 (K), D19.1 (K), D22.1 (K), F1.1
unnamed: F1.2, JP1.1 (A)
unnamed: C21.1, C22.1, U1.5 (VOUT), VBACKUP.1.1 (A)
VBACKUP: VBACKUP.1.2 (B); also elsewhere on the board
VIN: D19.2 (A); also elsewhere on the board
VUSB1: D18.2 (A); also elsewhere on the board
VUSB2: D22.2 (A); also elsewhere on the board

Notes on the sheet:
Voltage Regulation - RT9080-3.3
Power Mux
Voltage Regulation - AP7361C-3.3V
Open jumper when connecting external battery or power

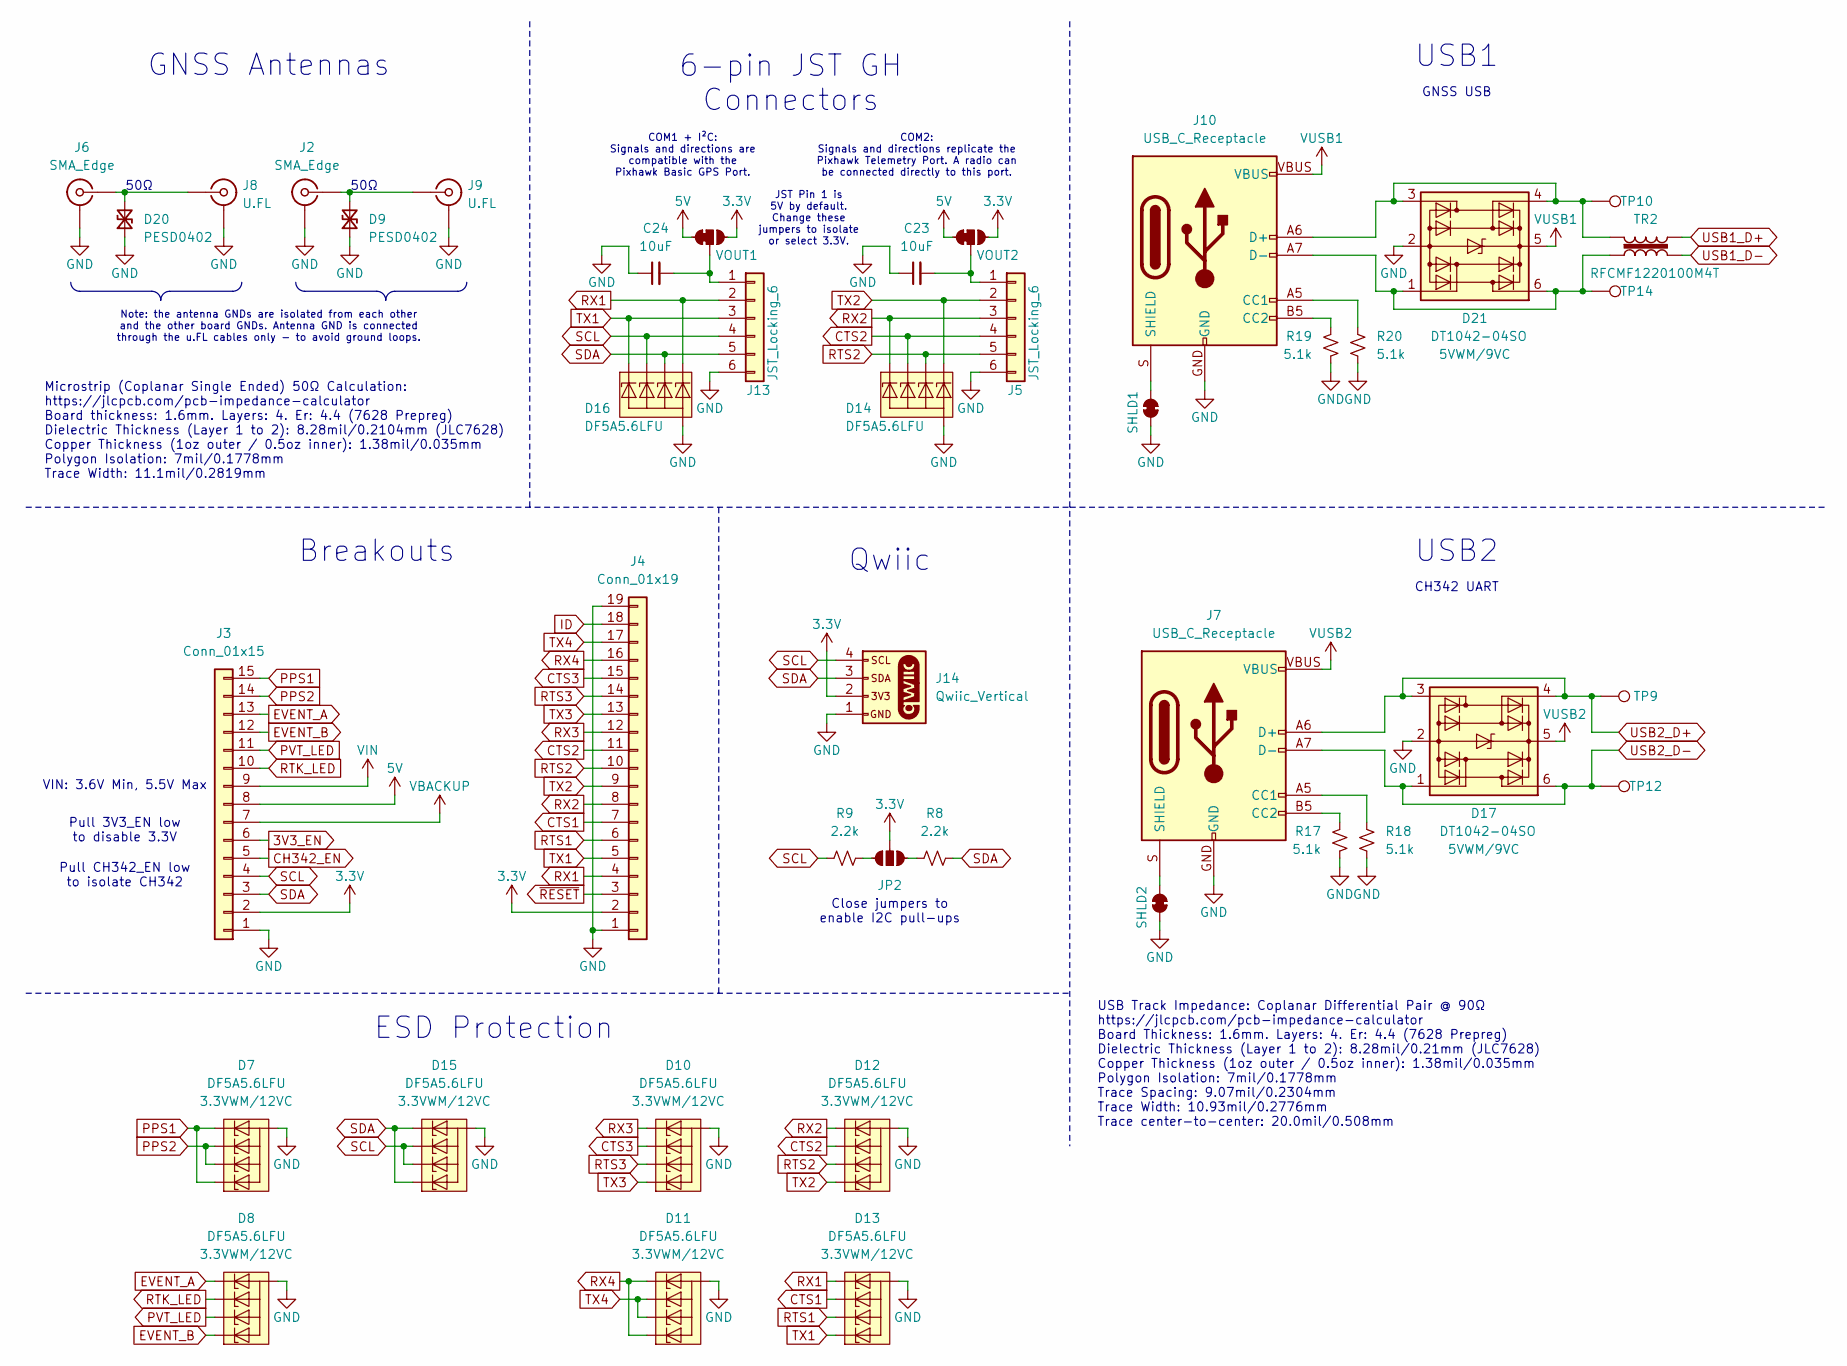
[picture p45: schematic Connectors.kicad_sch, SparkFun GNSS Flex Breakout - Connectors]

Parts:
C23, C24: 10uF; C_0603_1608Metric; Voltage 10V; Tolerance 20%
D7, D8, D10, D11, D12, D13, D14, D15, D16: DF5A5.6LFU; SOT-353; Rating 3.3VWM/12VC
D9, D20: PESD0402; C_0402_1005Metric; Rating 14VWM/40VC
D17, D21: DT1042-04SO; SOT23-6; Rating 5VWM/9VC
J2, J6: SMA_Edge
J3: Conn_01x15; 1x15
J4: Conn_01x19; 1x19
J5, J13: JST_Locking_6; JST_SMD_1.25mm-6_Locking
J7, J10: USB_C_Receptacle; USB-C_16
J8, J9: U.FL
J14: Qwiic_Vertical; JST_SMD_1.0mm-4_Vertical_Black
JP2: Jumper_3_NO
R8, R9: 2.2k; R_0603_1608Metric
R17, R18, R19, R20: 5.1k; R_0603_1608Metric
SHLD1, SHLD2: Jumper_2_NC_Trace
TP9, TP10, TP12, TP14: 1.25mm; TestPoint-1.25mm
TR2: RFCMF1220100M4T
VOUT1, VOUT2: Jumper_3_NC-1_Trace

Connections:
3.3V: J3.2, J4.2, J14.2, JP2.2 (B), VOUT1.3 (C), VOUT2.3 (C); also elsewhere on the board
3V3_EN: J3.6; also elsewhere on the board
5V: J3.8, VOUT1.1 (A), VOUT2.1 (A); also elsewhere on the board
CH342_EN: J3.5; also elsewhere on the board
CTS1: D13.4 (K3), J4.7; also elsewhere on the board
CTS2: D12.4 (K3), D14.3 (K2), J4.11, J5.4; also elsewhere on the board
CTS3: D10.4 (K3), J4.15; also elsewhere on the board
EVENT_A: D8.5 (K4), J3.13; also elsewhere on the board
EVENT_B: D8.1 (K1), J3.12; also elsewhere on the board
GND: C23.1, C24.1, D7.2 (A), D8.2 (A), D9.1 (A1), D10.2 (A), D11.2 (A), D12.2 (A), D13.2 (A), D14.2 (A), D15.2 (A), D16.2 (A), D17.2 (GND), D20.1 (A1), D21.2 (GND), J2.2 (Ext), J3.1, J4.1, J4.19, J5.6, J6.2 (Ext), J7.GND, J8.2 (Ext), J9.2 (Ext), J10.GND, J13.6, J14.1, R17.1, R18.1, R19.1, R20.1, SHLD1.1 (A), SHLD2.1 (A); also elsewhere on the board
ID: J4.18; also elsewhere on the board
unnamed: D9.2 (A2), J2.1 (In), J9.1 (In)
unnamed: D20.2 (A2), J6.1 (In), J8.1 (In)
unnamed: D21.1 (I/O1), D21.6 (I/O4), J10.A7 (D-), J10.B7 (D-), TP14.1, TR2.1
unnamed: D21.3 (I/O2), D21.4 (I/O3), J10.A6 (D+), J10.B6 (D+), TP10.1, TR2.3
unnamed: C23.2, J5.1, VOUT2.2 (B)
unnamed: J7.A5 (CC1), R18.2
unnamed: J7.B5 (CC2), R17.2
unnamed: J7.S (SHIELD), SHLD2.2 (B)
unnamed: J10.A5 (CC1), R20.2
unnamed: J10.B5 (CC2), R19.2
unnamed: J10.S (SHIELD), SHLD1.2 (B)
unnamed: C24.2, J13.1, VOUT1.2 (B)
unnamed: JP2.1 (A), R8.1
unnamed: JP2.3 (C), R9.2
PPS1: D7.1 (K1), D7.5 (K4), J3.15; also elsewhere on the board
PPS2: D7.3 (K2), D7.4 (K3), J3.14; also elsewhere on the board
PVT_LED: D8.3 (K2), J3.11; also elsewhere on the board
RTK_LED: D8.4 (K3), J3.10; also elsewhere on the board
RTS1: D13.3 (K2), J4.6; also elsewhere on the board
RTS2: D12.3 (K2), D14.4 (K3), J4.10, J5.5; also elsewhere on the board
RTS3: D10.3 (K2), J4.14; also elsewhere on the board
RX1: D13.5 (K4), D16.5 (K4), J4.4, J13.2; also elsewhere on the board
RX2: D12.5 (K4), D14.1 (K1), J4.8, J5.3; also elsewhere on the board
RX3: D10.5 (K4), J4.12; also elsewhere on the board
RX4: D11.1 (K1), D11.5 (K4), J4.16; also elsewhere on the board
SCL: D15.3 (K2), D15.4 (K3), D16.3 (K2), J3.4, J13.4, J14.4, R9.1; also elsewhere on the board
SDA: D15.1 (K1), D15.5 (K4), D16.4 (K3), J3.3, J13.5, J14.3, R8.2; also elsewhere on the board
TX1: D13.1 (K1), D16.1 (K1), J4.5, J13.3; also elsewhere on the board
TX2: D12.1 (K1), D14.5 (K4), J4.9, J5.2; also elsewhere on the board
TX3: D10.1 (K1), J4.13; also elsewhere on the board
TX4: D11.3 (K2), D11.4 (K3), J4.17; also elsewhere on the board
USB1_D+: TR2.4; also elsewhere on the board
USB1_D-: TR2.2; also elsewhere on the board
USB2_D+: D17.3 (I/O2), D17.4 (I/O3), J7.A6 (D+), J7.B6 (D+), TP9.1; also elsewhere on the board
USB2_D-: D17.1 (I/O1), D17.6 (I/O4), J7.A7 (D-), J7.B7 (D-), TP12.1; also elsewhere on the board
VBACKUP: J3.7; also elsewhere on the board
VIN: J3.9; also elsewhere on the board
VUSB1: D21.5 (VCC), J10.VBUS; also elsewhere on the board
VUSB2: D17.5 (VCC), J7.VBUS; also elsewhere on the board
~RESET: J4.3; also elsewhere on the board

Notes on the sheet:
Breakouts
USB1
USB Track Impedance: Coplanar Differential Pair @ 90Ω https://jlcpcb.com/pcb-impedance-calculator Board Thickness: 1.6mm. Layers: 4. Er: 4.4 (7628 Prepreg) Dielectric Thickness (Layer 1 to 2): 8.28mil/0.21mm (JLC7628) Copper Thickness (1oz outer / 0.5oz inner): 1.38mil/0.035mm Polygon Isolation: 7m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
50Ω
Close jumpers to enable I2C pull-ups
CH342 UART
COM1 + I²C: Signals and directions are compatible with the Pixhawk Basic GPS Port.
Pull 3V3_EN low to disable 3.3V
GNSS Antennas
JST Pin 1 is 5V by default. Change these jumpers to isolate or select 3.3V.
GNSS USB
COM2: Signals and directions replicate the Pixhawk Telemetry Port. A radio can be connected directly to this port.
Pull CH342_EN low to isolate CH342
USB2
Microstrip (Coplanar Single Ended) 50Ω Calculation: https://jlcpcb.com/pcb-impedance-calculator Board thickness: 1.6mm. Layers: 4. Er: 4.4 (7628 Prepreg) Dielectric Thickness (Layer 1 to 2): 8.28mil/0.2104mm (JLC7628) Copper Thickness (1oz outer / 0.5oz inner): 1.38mil/0.035mm Polygon Isolation: 7m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
Note: the antenna GNDs are isolated from each other and the other board GNDs. Antenna GND is connected through the u.FL cables only - to avoid ground loops.
6-pin JST GH Connectors
ESD Protection
VIN: 3.6V Min, 5.5V Max
Qwiic

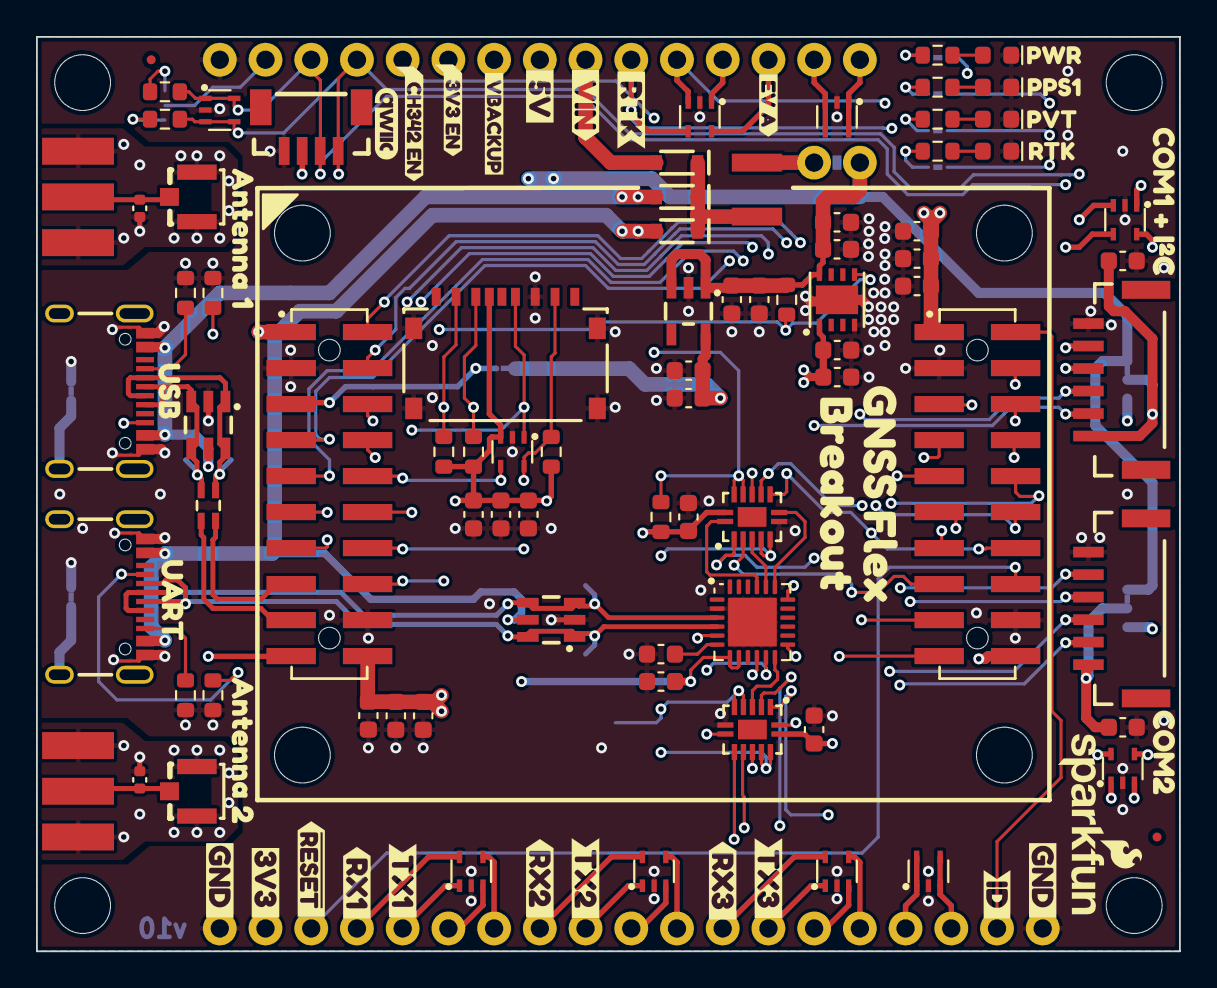
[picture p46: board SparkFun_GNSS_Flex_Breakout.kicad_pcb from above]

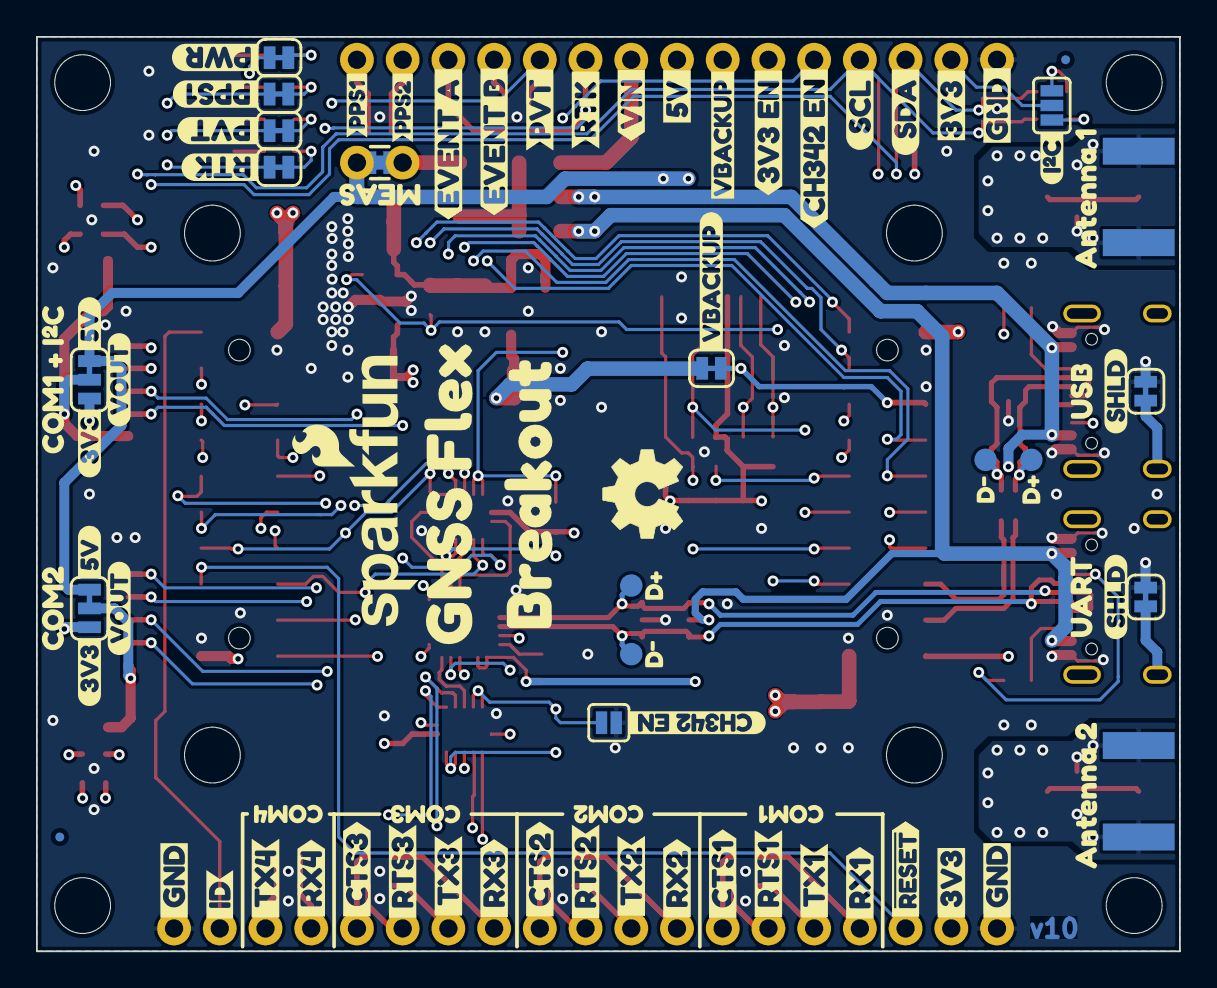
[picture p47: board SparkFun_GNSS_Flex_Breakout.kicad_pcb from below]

Board: 4 copper layers, 63.5 x 50.8 mm, 207 parts (85 on the bottom side), 75 nets.

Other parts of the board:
Ref**: Val**; OSHW_Logo_5mm
kibuzzard-67D04D07: G***; kibuzzard-67D04D07
kibuzzard-67D04D20: G***; kibuzzard-67D04D20
kibuzzard-67D04D30: G***; kibuzzard-67D04D30
kibuzzard-67D04E88: G***; kibuzzard-67D04E88
kibuzzard-67D022A2: G***; kibuzzard-67D022A2
kibuzzard-67D022AC: G***; kibuzzard-67D022AC
kibuzzard-67D044ED, kibuzzard-67D044ED#2: G***; kibuzzard-67D044ED
kibuzzard-67D045AD, kibuzzard-67D045AD#2: G***; kibuzzard-67D045AD
kibuzzard-67D045C9: G***; kibuzzard-67D045C9
kibuzzard-67D045EC: G***; kibuzzard-67D045EC
kibuzzard-67D046A8: G***; kibuzzard-67D046A8
kibuzzard-67D046B5: G***; kibuzzard-67D046B5
kibuzzard-67D046BD: G***; kibuzzard-67D046BD
kibuzzard-67D046CC: G***; kibuzzard-67D046CC
kibuzzard-67D046F7: G***; kibuzzard-67D046F7
kibuzzard-67D046FF: G***; kibuzzard-67D046FF
kibuzzard-67D171AB, kibuzzard-67D171AB#2: G***; kibuzzard-67D171AB
kibuzzard-67D171E5, kibuzzard-67D171E5#2: G***; kibuzzard-67D171E5
kibuzzard-67D1674C: G***; kibuzzard-67D1674C
kibuzzard-67D02274: G***; kibuzzard-67D02274
kibuzzard-67D03584: G***; kibuzzard-67D03584
kibuzzard-67D04501: G***; kibuzzard-67D04501
kibuzzard-67D04612: G***; kibuzzard-67D04612
kibuzzard-67D04639: G***; kibuzzard-67D04639
kibuzzard-67D04669: G***; kibuzzard-67D04669
kibuzzard-67D05112, kibuzzard-67D05112#2: G***; kibuzzard-67D05112
kibuzzard-67D16775: G***; kibuzzard-67D16775
kibuzzard-67DAC0B5, kibuzzard-67DAC0B5#2: G***; kibuzzard-67DAC0B5
kibuzzard-67E6AD3C, kibuzzard-67E6AD3C#2: G***; kibuzzard-67E6AD3C
kibuzzard-67E6AD12, kibuzzard-67E6AD12#2: G***; kibuzzard-67E6AD12
kibuzzard-67E6B1CF, kibuzzard-67E6B1CF#2: G***; kibuzzard-67E6B1CF
kibuzzard-67E6B1E0, kibuzzard-67E6B1E0#2: G***; kibuzzard-67E6B1E0
kibuzzard-67E6B4F7: G***; kibuzzard-67E6B4F7
kibuzzard-67E6B5D1: G***; kibuzzard-67E6B5D1
kibuzzard-67E6B5D6: G***; kibuzzard-67E6B5D6
kibuzzard-67E6B5E0: G***; kibuzzard-67E6B5E0
kibuzzard-67E6B5E7: G***; kibuzzard-67E6B5E7
kibuzzard-67E6B70A: G***; kibuzzard-67E6B70A
kibuzzard-67E6B547: G***; kibuzzard-67E6B547
kibuzzard-67E6B575: G***; kibuzzard-67E6B575
kibuzzard-67E6B720: G***; kibuzzard-67E6B720
kibuzzard-67E6B983: G***; kibuzzard-67E6B983
kibuzzard-67E6BA59: G***; kibuzzard-67E6BA59
kibuzzard-67E6BA73: G***; kibuzzard-67E6BA73
kibuzzard-67E6BA93: G***; kibuzzard-67E6BA93
kibuzzard-67E6BABA: G***; kibuzzard-67E6BABA
kibuzzard-67E6BAD6: G***; kibuzzard-67E6BAD6
kibuzzard-67E6BB49: G***; kibuzzard-67E6BB49
kibuzzard-67E6BB64: G***; kibuzzard-67E6BB64
kibuzzard-67E6BBAF: G***; kibuzzard-67E6BBAF
kibuzzard-67E6BBC6: G***; kibuzzard-67E6BBC6
kibuzzard-67E6C8C9: G***; kibuzzard-67E6C8C9
kibuzzard-67E6C8CF: G***; kibuzzard-67E6C8CF
kibuzzard-67E6C641: G***; kibuzzard-67E6C641
kibuzzard-67E68AA4: G***; kibuzzard-67E68AA4
kibuzzard-67E68AF7: G***; kibuzzard-67E68AF7
kibuzzard-67E68BE1: G***; kibuzzard-67E68BE1
kibuzzard-67E686E5: G***; kibuzzard-67E686E5
kibuzzard-67E688B9: G***; kibuzzard-67E688B9
kibuzzard-67E688C1: G***; kibuzzard-67E688C1
kibuzzard-67E688C9: G***; kibuzzard-67E688C9
kibuzzard-67E688D0: G***; kibuzzard-67E688D0
kibuzzard-67E689B5: G***; kibuzzard-67E689B5
kibuzzard-67E689EA: G***; kibuzzard-67E689EA
kibuzzard-67E68821: G***; kibuzzard-67E68821
kibuzzard-67EE9EE3, kibuzzard-67EE9EE3#2: G***; kibuzzard-67EE9EE3
kibuzzard-67EE9EFF, kibuzzard-67EE9EFF#2: G***; kibuzzard-67EE9EFF
kibuzzard-67EEB40C: G***; kibuzzard-67EEB40C
kibuzzard-67EEB400: G***; kibuzzard-67EEB400
kibuzzard-67EFA2E8: G***; kibuzzard-67EFA2E8
kibuzzard-67EFA2F1: G***; kibuzzard-67EFA2F1
kibuzzard-67EFDE56: G***; kibuzzard-67EFDE56
kibuzzard-67EFEB6F: G***; kibuzzard-67EFEB6F
kibuzzard-67EFEB92: G***; kibuzzard-67EFEB92
kibuzzard-67F7B6D7: G***; kibuzzard-67F7B6D7
kibuzzard-67F7B700: G***; kibuzzard-67F7B700
kibuzzard-67F7C8FB: G***; kibuzzard-67F7C8FB
kibuzzard-67F7C94B: G***; kibuzzard-67F7C94B
kibuzzard-67F7C97D: G***; kibuzzard-67F7C97D
kibuzzard-67F7C969: G***; kibuzzard-67F7C969
kibuzzard-67F7C991: G***; kibuzzard-67F7C991
kibuzzard-682202FA: G***; kibuzzard-682202FA
kibuzzard-6822032F: G***; kibuzzard-6822032F
kibuzzard-68220336: G***; kibuzzard-68220336

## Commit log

2025-03-28 Add Hardware - ready for airwire review
    [Connectors.kicad_sch, Power.kicad_sch, SparkFun_GNSS_Flex_Breakout.kicad_pcb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]
2025-03-29 Update QFN-14 3D model. Nudge USB connectors
    [SparkFun_GNSS_Flex_Breakout.kicad_pcb, SparkFun_GNSS_Flex_Breakout.kicad_sch]
2025-04-03 Routing WIP
    [Connectors.kicad_sch, Power.kicad_sch, SparkFun_GNSS_Flex_Breakout.kicad_pcb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]
2025-04-04 Routed and panelized
    [Connectors.kicad_sch, SparkFun_GNSS_Flex_Breakout.kicad_pcb, SparkFun_GNSS_Flex_Breakout.kicad_sch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]
2025-04-10 Updates after proto review
    [Connectors.kicad_sch, Power.kicad_sch, SparkFun_GNSS_Flex_Breakout.kicad_pcb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]
2025-04-22 PCB v02 - with corrected regulator footprint
    [Connectors.kicad_sch, Power.kicad_sch, SparkFun_GNSS_Flex_Breakout.kicad_pcb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]
2025-05-12 v10 PCB - correct PVT and RTK LEDs, and VBACKUP silk
    [SparkFun_GNSS_Flex_Breakout.kicad_pcb, SparkFun_GNSS_Flex_Breakout.kicad_sch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]
2025-09-18 Docs - Initial Draft
    [SparkFun_GNSS_Flex_Breakout.kicad_pcb]
2025-10-10 Update 3D model
    Refactored the 3D model for all the GNSS Flex boards to a new standardization
    Eliminated the manual adjustments required for any new 3D models
    - Modified the old models, so any new models can be adopted without any changes after they have been optimized

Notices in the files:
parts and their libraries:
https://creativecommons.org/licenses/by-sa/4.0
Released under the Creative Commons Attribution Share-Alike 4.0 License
